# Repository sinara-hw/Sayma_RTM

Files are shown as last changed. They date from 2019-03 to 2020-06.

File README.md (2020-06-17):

# Sayma_RTM
RTM board with 8-channel GS/s DAC, 125MS/s ADC and flexible clock circuit

## Design Files

Design files (schematics, PCB layouts, BOMs) can be found at [Sayma_RTM/Releases](https://github.com/sinara-hw/Sayma_RTM/releases).

## Wiki

More information can be found on the [wiki](https://github.com/sinara-hw/Sayma_RTM/wiki).

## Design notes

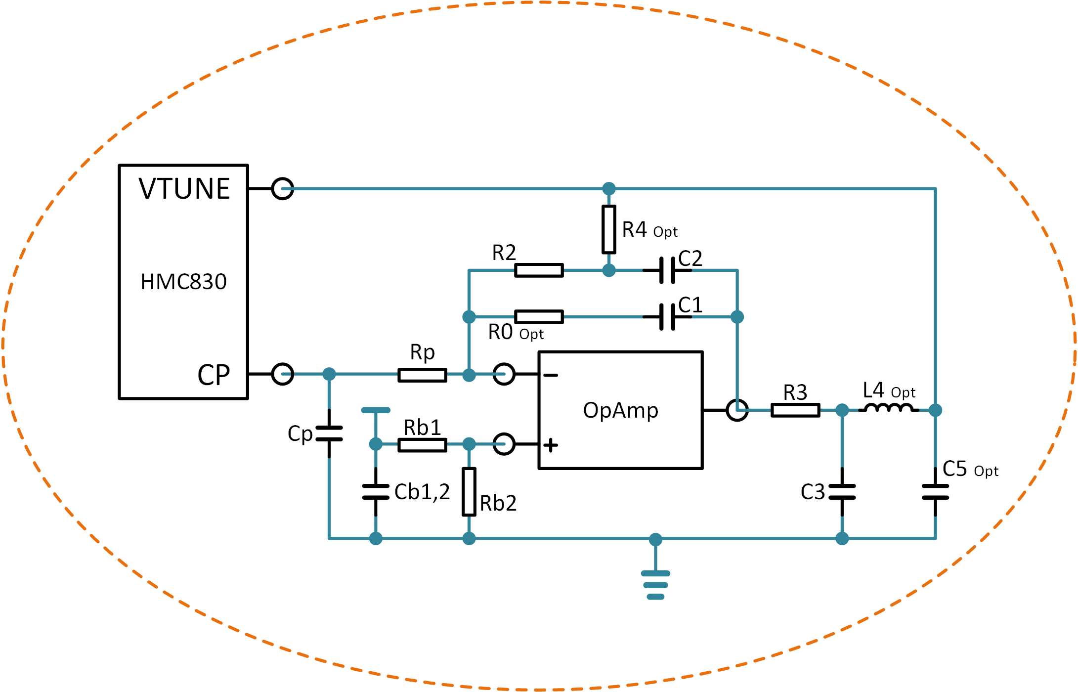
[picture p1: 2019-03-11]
HMC_830_FILTER.png

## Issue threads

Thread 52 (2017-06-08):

Sayma RTM - version 1 errata & tests

gkasprow, 2017-06-08:
Mechanical:
- [ ] SMA connector clearance with PCB edge - move it 100um outside
- [ ] Align J6, J7
- [ ] adjust 4-th upper  panel SMA hole
- [ ] move T7 away from the board edge
- [ ] J16, J18, J55, J66 i J64  not covered vias under connectors
- [ ] fix footprint of interdigitated capacitors

Silkscreen:
- [ ] Label on both sides of PCB for name of J1, J2, J73, J74.
- [ ] Dot marking pin1 J1, J2, J5, J7, J8, J9, J73, J74
- [ ] AFE slot names are not visible when Allaki are installed
- [ ] AFE slot names on both sides of PCB
- [ ] When the Allaki is mounted, the IN/OUT silkscreen faces the Sayma RTM PCB and makes it useless. Put it on the other layer that is visible when the card is mounted.
- [ ] add description to LD12, LD5, LD10, LD11, LD3

BOM:
- [x] R20, R21 = DNP
- [x] R269=1k

I2C:
- [x] replace MAX6642ATT90+T with MAX6642ATT98+T on RTM - change I2C address from 0x48 to 0x4C
- [x] connect some I2C pullups to P3V3 instead of P3V3MP

Power supply:
- [x] add another LDO for 1.2V (SVDD12)
- [x] connect 2V and 4V power module FB path to GND
- [x] fix power sequencing of negative SEPIC converter - either by addin 1uF cap to SS or starting negative converter after positive one.

Annotations:
- [x] IC57 address is 0x4B - change comment on schematics (PK: 0x49 is correct)
- [x] Zero-index all channels (DACs, ADCs, SFPs, SMAs, mezzanines, etc.)

JTAG:
- [ ] consider adding config FLASH
- [x] wire M[2:0] as 0b111 for slave serial configuration (#249)
- [x] swap FPGA config lines - DIN with MOSI (probably),
- [x] make sure config mode is set correctly.

Clocks:
- [x] HMC7043 has active high reset while SI5324 is active low. ~Add negator to one of them or tie HMC RST to GND~ give HMC7043 its own dedicated reset line to avoid noise issues during initialization.
- [x] short RSV* pins of HMC7043 to GND
- [x] add 10k pulldown on PLL chip CLK and SEN lines to make sure that logic state is well defined and FPGA can setup correct SPI protocol.
- [x] add CLK and SYSREF termination
- [x] SD pins of the LTC6957 clock buffer mus be grounded
- [x] HMC830 loop filter layout forms quite a large loop. Please try to make this smaller for EMI reasons.
- [x] HMC830 "NC" pins are currently floating in our design. Copy the [eval board](http://www.analog.com/media/en/technical-documentation/evaluation-documentation/hmc830lp6ge_eval_pcb_schematic.pdf) for these connections.
- [x] add HMC7043 output bias FET that disables clocks before configuration to get rid of RF noise
- [x] pullup/pulldown on HMC830 CS/clk line to prevent it from getting stuck in the wrong SPI mode
- [x] So, to be sure, I think we need separate pins for: Si5324 RST; HMC7043 RST; HMC7043 output enable FETs.
- [x]  We also need to make sure that all these lines (as well as the HMC830 CS) have the right pull ups/pull downs to put things in the correct default state on power up.
- [x] PLL locked LED for the HMC830, maybe leds for the clock muxes to indicate the clock source.

DAC:
- [x] missing 49R9 0201 resistors at the DAC outputs
- [x] connect VTT to 1.2V

Test points:
- [x] add GND and i2C testpoints
- [x] More test points, e.g. on all SPI busses, power rails, JTAG, PLL v tune, etc! Also some ground points to attach a scope to (maybe use pcb mounted test loops for some of these?)
- [x] Lots of test points (all SPI/I2C lines)

Other:
- [x] RTM: short VREFN and VREFP to GND, DNP C546 to enable internal ADC reference
- [ ]  consider adding 0R resistors between ICs and control lines (SPI, enable, etc) to allow easier debug/rework
- [x] add LVDS terminators (SSTL)

gkasprow, 2019-03-11:
moving mechanical issues to #46 and closing

Closed 2019-03-11.

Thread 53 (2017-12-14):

put BaseMod IN/OUT silkscreen on the other layer

sbourdeauducq, 2017-12-14:
When the Allaki is mounted, the IN/OUT silkscreen faces the Sayma RTM PCB and makes it useless. Put it on the other layer that is visible when the card is mounted.

gkasprow, 2019-03-11:
moved to #46

Closed 2019-03-11.

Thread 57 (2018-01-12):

Sayma v2: more test points

jbqubit, 2018-01-12:
From #408. @gkasprow More test points on Sayma v2.0, please! Particularly on all the SPI buses.

hartytp, 2019-03-14:
Could you have a go at this today please? I’ll do my review after it’s done

jbqubit, 2019-03-15:
@gkasprow Please implement change or give update. We'd all like to see pending changes to RTM complete and design frozen.

gkasprow, 2019-03-16:
Let's add missing test points to the issues and go on with the review.

hartytp, 2019-03-16:
Most important are the HMC830 and HMC7043 SPI. I'd also ideally like to have 0R resistors between the HMC chips and the FPGA for debugging (e.g. if we need to disconnect some signal).

Most analog power lines should have test points.

All I2C signals

hartytp, 2019-03-22:
AFE power supplies, I2C

gkasprow, 2019-04-08:
fixed

Closed 2019-04-08.

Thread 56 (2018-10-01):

sayma: heatsinks

hartytp, 2018-10-01:
With the DACs running at 2.4GHz they get scorching hot, even with decent air flow. Might be worth small heat sinks in the next version (also for the RTM FPGA?).

gkasprow, 2019-04-08:
I managed to place 17x17x2mm heat sinks. Even 3mm ones would fit but 2mm ones are COTS

gkasprow, 2019-04-08:
drawing
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

Closed 2019-04-08.

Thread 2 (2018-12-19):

test: measure DAC-DAC phase drift

jbqubit, 2018-12-19:
Measure and document relative DAC phase noise ([ST3](https://github.com/sinara-hw/sinara/issues/601)) for pair of Sayma in same rack. Compare three outputs.
- between channels on the same DAC
- between channels on adjacent DACs on the same RTM
- between channels on adjacent RTMs

Measure within 0.1 mHz of carrier using Microsemi 5125A.

jbqubit, 2018-12-19:
I asked analog Tech Support about drift. Here's their response.

> What is the dependence of signal propagation on temperature? Suppose I have two AD9154 chips that have a common dac clock and are initially phase aligned and producing 400 MHz tone. What is the relative phase if one AD9154 temperature increases by 1 C?

> I do not have a good answer here frankly. To quantify temperature drift, typically more than one part needs to be tested. We have little to no capacity to set this up at the moment.
Two AD9154’s (or any other identical generics) would drift in the same direction, and the rate would be similar as well, assuming the same production lot. So the relative phase will likely stay the same, especially with only 1*C increase. The really interesting aspect would be if there is a temp gradient between two devices from two different lots (monte carlo of sorts).
Temperature is inherently non-linear. So the slope due to a 1*C change will be different depending on the starting temp. Likely more so on the hot end. All in all, you would need to collect considerably more data than on a single part.  Going forward, we will have more temperature data on this class of parts.

So should check between several pairs of AD9154.

hartytp, 2018-12-19:
If you want to measure drift then the simplest way might be to just run the DACs at the same frequency then beat them against each other on a mixer and use a high-precision DMM to log the phase (given by the DC level). This is what we typically do and it works well.

Closed 2019-05-27.

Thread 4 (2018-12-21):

bigger FPGA

hartytp, 2018-12-21:
Context:
- there is currently a 15T on Sayma RTM which is pretty tiny
- for DRTIO we need to add Satman. Currently, that should be fine but it will require some optimisation to reduce firmware size
- adding a bigger FPGA will make it easier to get DRTIO going and reduces risks
- we can always move back to a smaller pin-compatible FPGA in a future design revision to save costs

@sbourdeauducq what size of FPGA do you think we should go for? 50T? Since this is still a prototype, let's err on the side of having too big an FPGA rather than too small.

@gkasprow what's the biggest pin-compatible FPGA we can stick on Sayma RTM?

jordens, 2018-12-21:
The 50T is pin compatible. But as mentioned before that might not be needed at all since the bitstream is the same except for the chip name.

hartytp, 2018-12-21:
So, the suggestion is bitstream hacking to make a 50T bitstream work on the 15T (which is the same silicon)? What's the cost difference between the two FPGAs? Is it worth the hassle of bitstream hacking?

hartytp, 2018-12-21:
Anyway, right now my preference is to go with whatever is least effort and gets RF out of Sayma quickest. Once Sayma works and we've gauged the level of interest we can focus more on cost optimisation.

jordens, 2018-12-21:
Place a 50T for now if the availabliity is ok and keep in mind that moving back to a 15T will require software infrastructure changes.

sbourdeauducq, 2018-12-23:
Well, with some optimization it may even fit within the 15T limitations that Xilinx made up. But 50T on proto sounds good.

jbqubit, 2018-12-26:
50T sounds like the lowest risk option. @gkasprow @marmeladapk Is it too late for this change to the BOM?

gkasprow, 2018-12-28:
I will check if they are 100% compatible. Usually this involves generation of new symbol and comparison pin by pin because not always migration is that straightforward.

marmeladapk, 2018-12-28:
According to Xilinx they should are pin compatible, however we should rerun power estimator and adjust power delivery accordingly.

gkasprow, 2018-12-28:
They usually are, but It happened to me that some IOs were swapped during migration to bigger chip or not present in smaller packages. So it is not always that simple.

gkasprow, 2019-01-01:
Can we use XC7A35T-1CSG325 instead?

gkasprow, 2019-01-01:
It's hard to get XC7A50T in CSG325 package

sbourdeauducq, 2019-01-06:
Also use a faster speed grade, -1 does not meet timing for 150MHz RTIO frequency.

sbourdeauducq, 2019-01-06:
15, 35 and 50 are the same silicon so it doesn't matter so much which one you pick...

jbqubit, 2019-01-08:
@sbourdeauducq   Please concur if you're happy with XC7A35T-2CSG325.

@gkasprow Are you comfortable that the risk is low enough for this change?

- [ ] re-run power estimator
- [ ] pin-by-pin check of new symbol

gkasprow, 2019-01-08:
The power supply is designed with a lot o margin. I can increase the current limit even by a factor of 5.

jbqubit, 2019-01-11:
@jordens Does your comment mean that @sbourdeauducq signed off on the use of 35T-3?

gkasprow, 2019-02-25:
XC7A35T-3CSG325 used.

kaolpr, 2019-07-18:
Long lead time for XC7A35T-3CSG325E (~14 weeks).

@sbourdeauducq @jordens Do you agree to use XC7A50T-3CSG325 only for the current production?

sbourdeauducq, 2019-07-18:
OK with me. The only important thing is the speed grade 3.

jbqubit, 2019-07-31:
XC7A50T-3CSG325 is fine by me.

jbqubit, 2019-08-19:
@gkasprow Please indicate how you're proceeding with this and close.

gkasprow, 2019-08-19:
We installed XC7A50T-3CSG325. It's the same silicon anyway.

Closed 2019-08-19.

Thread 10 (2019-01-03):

v2.0rc1 schematic cosmetics

hartytp, 2019-01-03:
Thanks for posting the new schematic revision @gkasprow! Posting small cosmetic issues here:
- [ ] remove annotation "Matching between the ... " and "SYSREF is matched to its CLK ... "
- [ ] annotaiton "other diff lines: LVDS" is a bit odd, since all other diff lines are now explicitly named LVDS. Just remove this line from the annotation?
- [ ] clarify what "shared IOs" means. Shared with what?
- [ ] Missing overview page?

hartytp, 2019-01-03:
- [ ] add annotation with frequency of OSC2

hartytp, 2019-01-03:
- [ ] HMC_RESET -> HMC830_RESET

hartytp, 2019-01-03:
- [ ] remove "SYSREF is matched to its CLK (a.k.a. DEVICECLK) to better than 100 ps" this no longer makes sense

atcher0, 2019-01-14:
- [ ] DAC_CFG buses are not zero-indexed
- [ ] HMC_RESET and HMC_SPI_GPIO lines are not used (CLK_DIST_CFG bus)
- [ ] HMC830_SPI_SEN != HMC_SPI_SEN (clock distribution page)
- [ ] no information about FPGA configuration settings
- [ ] many FPGA not connected pins are not marked NC
- [ ] OSC2 is placed on schematic without part number (+ no language describing use case)
- [ ] pages are not numbered consecutively

marmeladapk, 2019-01-14:
- [ ] Add annotations about TPSM84824: switching frequency (450 kHz) and soft start (2,4 ms)

gkasprow, 2019-02-26:
@hartytp what overview page would you like?

hartytp, 2019-02-26:
Something with a system BD that makes it clear what blocks we have in the design and how they connect together. Whatever you think is best though.

hartytp, 2019-03-16:
@gkasprow the new schematics are really beautiful. Very nicely annotated (comments about clocking regions for LVDS lines, colour coding for busses etc). Really well done on that :)

hartytp, 2019-03-16:
We can delete Weida's diagram from the schematics, since there isn't anything in there that isn't already in the schematics.

hartytp, 2019-03-16:
- [ ] worth adding an annotation on the HMC7043 that the FETs are used to avoid sending broadband noise to the FPGA before the IC is configured.

gkasprow, 2019-03-16:
Thanks. It's a side effect of switching to Altium :)

hartytp, 2019-03-16:
- [ ]  maybe add an annotation about the purpose of the bleed FETs on the HMC 830 supply (took me a minute to remember why they're there)

marmeladapk, 2019-04-05:
- [ ] P5V0_LDO_IN  (near IC15) should be P4V0...

hartytp, 2019-05-27:
@gkasprow are you happy with the overview page here? If so, let's close this issue.

marmeladapk, 2019-08-30:
[ ] Rename xVDD12 to xVDD13 on dac schematics?

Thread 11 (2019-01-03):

LT3045

hartytp, 2019-01-03:
- [x] Min output capacitor is 10uF (ensure decrease in capacitance from DC bias is taken into account)
- [x] check input capacitors as well as set capacitance (do we need a 100nF along with the electrolytic)?

gkasprow, 2019-02-27:
I replaced 4.7u with CC0805_22UF_16V_10%_X5R
The input cap is 4.7uF

Closed 2019-02-27.

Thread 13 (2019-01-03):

Sysref driving

hartytp, 2019-01-03:
@gkasprow how do you want to drive the AD9154 SYSREF? IIRC it should ideally be driven DC coupled with a common-mode voltage of 600mV (but someone should check this during the design review). That's not directly compatible with LVPECL without a RC termination network.

hartytp, 2019-01-03:
- [ ] even though this will be DC coupled, please ensure that there are suitable pads that can be used to add AC coupling capacitors later on if we find it necessary

hartytp, 2019-01-09:
cf https://github.com/sinara-hw/Sayma_RTM/issues/17

hartytp, 2019-01-09:
NB fwiw, the eval board has the SYSREF AC coupled, with a test point used to drive/probe the DC level.

IIRC the data sheet implies that SYSREF should be DC coupled where possible.

I would like to ensure that we can drive SYSREF either DC or AC coupled (choice by population options), with DC coupling being the default choice.

gkasprow, 2019-01-09:
If SYSREF is going to be a non-50% duty cycle, we must use DC coupling. We must make sure DAC accepts LVPECL common model

hartytp, 2019-01-09:
> We must make sure DAC accepts LVPECL common model

I don't think it does. IIRC the pin self-biases to 600mV (there is a figure in the data sheet that shows the simplified schematic for the input configuration), which is the common-mode voltage it's designed to work at. I don't think the common-mode voltage of LVPECL/CML will do the job.

marmeladapk, 2019-01-14:
Now SYSREF is AC coupled (and capacitors don't have values on schematics).

gkasprow, 2019-02-27:
well, not really. The high level of LVPECL can be even 2.4V. So out of the common mode of the DAC.
Do AC-coupling cause any issue? Certainly, we are not over-driving the inputs. I added the series 50Ohm resistors to lower the clock amplitude.

hartytp, 2019-02-27:
@gkasprow the thing I'm conscious of is that the default (self-biasing/AC coupling) DAC input common-mode bias voltage is only 600mV. I believe that it can work with other common-mode voltages, as indicated by the data sheet, but requires a larger swing to operate correctly. There is an equivalent circuit of the input stage that shows how this works.

So, I'm wary of DC coupling LVPECL in to the DAC unless we really think about it.

gkasprow, 2019-02-27:
So let's leave it as it is now.

hartytp, 2019-02-27:
@gkasprow can you confirm:
1. SYSREF is DC coupled into the DAC (although, let's make sure there are pads for AC coupling). IIRC currently SYSREF is AC coupled
2. DAC clocks and SYSREF are correctly terminated
3. which HMC7043 output standards is this designed to use (let's make sure that's annotated on the schematic)
4. that the common-mode voltage and voltage swing are appropriate for both the DAC clock and SYSREF

Once that's done we can close this issue

gkasprow, 2019-02-27:
to make SYSREF DC-coupled I have to lower the LVPECL output to less than 2V.
LVDS mode does not meet minimum 400mVpp DAC requirement.
So either we use CML mode that has VCC-1.6V common mode voltage or LVPECL with resistive divider.
I suggest using direct CML mode with series resistors that will reduce the swing
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
two 50R resistors should do the job and preserve common mode

gkasprow, 2019-02-27:
Let's keep the 200R DNP so we can always use them and replace 49R9 with 100nF and revert to AC coupling.

gkasprow, 2019-02-27:
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

hartytp, 2019-02-27:
Do you need to add termination to Vcc at the DAC then?

hartytp, 2019-02-27:
(if you're using CML for SYSREF that is)

hartytp, 2019-02-27:
Also, are you sure that 3.3-1.6=1.7V common-mode will work for the DAC SYSREF?

gkasprow, 2019-02-27:
It accepts it up to 2V so with reduced swing should work.

gkasprow, 2019-02-27:
HMC has internal termination for CML mode
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

hartytp, 2019-02-27:
Okay. Can you leave resistor pads so that we can make a divider between Vcc and GND if we need to modify the voltage swing/DC bias point.

gkasprow, 2019-02-27:
OK, I will add 2 DNP resistors to GND to make such divider.

Closed 2019-02-27.

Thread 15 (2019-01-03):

CDR clean 2

hartytp, 2019-01-03:
@sbourdeauducq do we need this, or can we just use use the MGT REF CLK? If we remove this signal, we can scrap a clock buffer to save some money/power/complexity in the clock tree

jbqubit, 2019-01-08:
@hartytp This isn't the time to try to optimize Sayma v2 money/power/complexity. The current plan is to keep the number of v1 vs v2 diffs to a minimum.

hartytp, 2019-01-08:
> The current plan is to keep the number of v1 vs v2 diffs to a minimum.

The purpose of this is not to minimise the number of design changes, it's to maximise the probability of arriving at a working design given the available resources.

While I appreciate the enthusiasm, I'm not connived the current spray of comments is entirely productive. Chill out and let's focus on having a solid technical strategy here rather than knee-jerk reactions.

hartytp, 2019-01-08:
Aside from the obvious point that unnecessary components can still introduce bugs and break an otherwise working design, they have to be checked carefully as part of the design review and then tested before the hardware is shipped. This all leads to delays. If this components is genuinely not going to be needed then it is likely to be quicker to remove it than to keep it.

jbqubit, 2019-01-08:
> I'm not connived the current spray of comments is entirely productive.

Please respond to my comments in the respective Issues.

jbqubit, 2019-01-09:
OK. Let's see what @sbourdeauducq says.

gkasprow, 2019-02-25:
Let's keep it as it is.

Closed 2019-02-25.

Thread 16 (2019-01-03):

WR?

hartytp, 2019-01-03:
@gkasprow would it be possible to add the same WR circuitry to the RTM that we have on the AMC? My long term aim it to be able to generate a high-stability DAC clock from the WR clock (via the AMC FPGA).

jbqubit, 2019-01-08:
@hartytp No more changes. Let @gkasprow focus on keeping track of bugs found during the design review. Please hold these suggestions until after Sayma v2.0.

hartytp, 2019-01-08:
@jbqubit

This is not a new addition to the project plan, it's finishing a job we've already agreed to do and have done most of the work for. There is no point at all having WR on the AMC if it's not also on the RTM, since that's where we actually need a good clock. The most time consuming part was designing WR for the AMC and reviewing that (already done), copying it to the RTM will be relatively quick.

jbqubit, 2019-01-09:
The point of a structured review process is to avoid pitfalls including feature creep. The time for lobbying to add new features to the design has passed. WR was added to the AMC as a secondary clock source to permit prototyping of DDMTD on Sinara hardware. It is not among my requirements in Sayma v2.0 and I'm not funding its development. As this change relates to a "long term" aspiration for Sayma let's discuss after Sayma v2.0 is working. It may be that it can be added to production hardware.

marmeladapk, 2019-01-09:
@jbqubit Well, technically I don't think that both m-labs and @hartytp signed of on HT1.5 in table. Also, I wouldn't call it a feature creep, this was discussed and, as @hartytp said, reviewed before. In schematics this change should be just replacing Si5324 sheet with one from AMC + adding I2C to FPGA. (@gkasprow correct me if I'm wrong)

TBH I'm not sure if there's a point in having WR only on AMC (I was surprised, that it wasn't present on RTM), after all we'd like to synchronize DAC output on Saymas, not just FPGA clocks. WR support on RTM could be of interest to other groups, which already use WR with MicroTCA.

Reviewers for clock schematics are me and @hartytp, and I just started checking issues in clock schematics. We can easily wait few more days and check something else in the meantime.

hartytp, 2019-01-09:
> WR was added to the AMC as a secondary clock source to permit prototyping of DDMTD on Sinara hardware

No, that's not why we added it here. WR will be prototyped on Kasli v1.2 not Sayma. I would not use a design as complex as Sayma to prototype this.

The point of adding WR on Sayma was to take the WR system we develop on Kasli and test its performance for clocking high-speed data converters. The clocking on Sayma, which will require high-stability reference clocks distributed to each RTM, is liable to turn into a bit of a mess without WR, which is why I'm keen to have a go at implementing it (and, indeed @dtcallcock an others have indicated that they would also value WR for this). We can't test this without WR on both the RTM and AMC. There is almost no point I can see in having WR on the AMC alone.

> It may be that it can be added to production hardware.

The whole point of prototyping is to prototype the system you want. Not to leave important sections (I would argue that in the long run WR will be important) out and then stick them on without testing for production.

> The point of a structured review process is to avoid pitfalls including feature creep. The time for lobbying to add new features to the design has passed.

This isn't adding a new feature, it's clarifying the scope of a feature already on the project plan. As far as I'm concerned, implementing WR on Sayma at all means implementing it on both AMC and RTM, otherwise it's just a waste of time.

WR is a block of hw that can be copied from one design to another relatively easily. The bulk of the time is spent designing that block, not copying it from the AMC to RTM. Putting it on the RTM is a small amount of extra work that allows us to make use of the work we've already done.

jordens, 2019-01-09:
@marmeladapk I think that WR on AMC is useful or even required for other users of Sayma_AMC.

sbourdeauducq, 2019-01-09:
> @hartytp No more changes.

@jbqubit What is the point of asking for reviews if you dismiss important comments like this one?
WR on RTM is needed to clock the DACs. Not having it there defeats its purpose entirely.

jordens, 2019-01-09:
I am a bit worried by the level of testing and integration that this (new) WR implementation will have seen (both in hardware and gateware/software) before we paste it on three boards roughly simultaneously. If we can't arrive at a trialed and tested design with integration at the PCB-level and the gateware/software level early enough, then we should at least invest significantly more time and resources into cleaning up, documenting, testing, reviewing, and integrating the current prototype.

hartytp, 2019-01-09:
@jordens that's fair.

The hardware has been quite extensively tested using the KC705 and DCXO evaluation boards. Phase noise and stability plots have already been posted. We've verified that it reliably acquires lock and maintains if over several days without issues (scope on infinite persist triggered from reference and monitoring recovered clock). I can provide additional documentation of the hardware configuration, for example by giving a list of FPGA connections used to implement WR if that helps.

The gateware/software for this was straight verilog + xilinx cores e.g. for I2C. A migen/misoc port is underway at the moment. FWIW, I can't think of any issues with Artiq integration that could be major showstoppers, beyond the usual requirements for transceiver/fabric clocking, but there is always a risk that we've missed something.

The gateware is mainly just a straightforward implementation of the CERN WR cores. The changes are:
- higher order loop filter
- loop filter implemented in DSP instead of soft CPU
- I2C dac + VCOs replaced with I2C DCXOs (programming words are longer than for DACs, so I2C busses must run at higher clock rates, but still below the max 1MHz clock rate)

One thing that does need doing is pulling all the data scattered across various places into a write up. We'll do that, but might not manage it before the Sayma deadline which is quite tight.

sbourdeauducq, 2019-02-02:
The pitiful results of some DDMTD attempts on the Ultrascale FPGA makes me think that we have to be careful about how we time signals with FPGAs. We cannot expect to route time-critical signals without precautions all around a large, noisy FPGA and get good performance.

* DDMTD on Ultrascale with one clock from the GTH and one clock from an I/O bank exhibits high peak-to-peak jitter and unexplained intermittent skews that are not corrected by averaging, when the FPGA is loaded by integrating SAWG. This renders it pretty much unusable in this configuration, unless workarounds are found (discussing with Xilinx).
* DDMTD on Ultrascale with both clocks from the same IO bank, and one on a GC pin, works a lot better, but I have done only limited testing (this is not interesting for Sayma DAC synchronization, since I could not figure out a good hardware hack to get relevant clocks with deterministic phases in the same IO bank).
* DDMTD on Artix-7 with both clocks from the same IO bank, and one on a GC pin, is looking good, no DDMTD failure found by firmware diagnostics after 506 Sayma reboots, reported jitter is low.

So we should make sure that all time-critical paths stay in the same I/O bank and also signals that go to MMCMs, BUFGs, etc. are using the correct GC pins.

Some more radical options:
* connect a AMC backplane transceiver pair to the RTM GTP (through the AMC and RTM connector), so we can bypass the Ultrascale FPGA for all time-critical functions if needed (i.e. run DRTIO directly from Metlino to Sayma RTM).
* add a small FPGA to Metlino that handles time-critical functions, like managing the WR PLL.

hartytp, 2019-02-02:
@sbourdeauducq thanks for the updates, that's helpful.

> DDMTD on Ultrascale with one clock from the GTH and one clock from an I/O bank exhibits high peak-to-peak jitter and unexplained intermittent skews that are not corrected by averaging, when the FPGA is loaded by integrating SAWG. This renders it pretty much unusable in this configuration, unless workarounds are found (discussing with Xilinx).

@WeiDaZhang correct me if I'm wrong, but that's a bit concerning isn't it, since this is the configuration that we have to use for clock recovery on Sayma (since one clock originates in the transceiver).

We did a lot of testing on the Kintex 7 and didn't see effects like this, but have no experience with ultrascale FPGAs.

> So we should make sure that all time-critical paths stay in the same I/O bank and also signals that go to MMCMs, BUFGs, etc. are using the correct GC pins.

I think the proposed implementation of DDMTD-based clock recovery on Sayma does this as far as possible (although if you see room for improvement then let me know!).

> connect a AMC backplane transceiver pair to the RTM GTP (through the AMC and RTM connector), so we can bypass the Ultrascale FPGA for all time-critical functions if needed (i.e. run DRTIO directly from Metlino to Sayma RTM).
>
> add a small FPGA to Metlino that handles time-critical functions, like managing the WR PLL.

The idea of adding timing FPGA on Metlino is potentially quite a nice one, might be worth trying to keep that option open as a future direction. I'd really like to build a version of Kasli with DDMTD + DCXO asap so we can develop the concept and give it a proper test in a simpler system before we make too many decisions about what to do on Metlino.

What about systems where we don't use Metlino, and control Sayma via SFP (this will be our primary use case for the foreseeable future)? In that case, I don't see an obvious remedy to avoid the ultra scale FPGA.

gkasprow, 2019-02-27:
I added WR to the RTM side.
Anything else do to in this issue?

hartytp, 2019-02-27:
Nope

Closed 2019-02-27.

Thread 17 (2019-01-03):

delay line termination

hartytp, 2019-01-03:
I don't understand the termination for the digital delay line:
- Why are R127 and R128 used for *DC* coupled LVPECL?
- Why is R129 necessary?
- Don't we need to apply a Vcc-2V=1V3 DC bias to the Vtt pin? Just use one of the standard RC networks for this

hartytp, 2019-01-03:
Similarly for the DFF:
- IIRC the CK and D lines of the MC100EP31DTG are **not** internally 50R terminated (they just have 75k) pull downs. So external termination is required
- there is a version of the DFF that has a differential LVPECL clock input. We might as well use that since we have a differential driver available (don't worry about this if it's hard to do, but it would be nice since better emi resistance)
- The CK input needs appropriate DC biasing since it's DC coupled (this could be AC coupled if it's easier)

gkasprow, 2019-02-25:
not relevant anymore

Closed 2019-02-25.

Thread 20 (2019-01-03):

clock probe points

hartytp, 2019-01-03:
Add UFL test points on the unused output of IC46 (AC coupled, with 200R biasing resistors). During noise debugging, it's really useful to be able to verify the clock noise at each step of the clock tree. We can DNP these in a future design revision

gkasprow, 2019-02-25:
done

Closed 2019-02-25.

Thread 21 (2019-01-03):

adf PLL review

hartytp, 2019-01-03:
Will complete this after testing. Howerver....
- [ ] remove the bias inductors. They increase the power by 1dB at high frequencies but kill the power at low frequencies. Not worth the hassle
- [ ] review the HMC1060LP3E connections
- [ ] @gkasprow if possible, I'd like to scrap IC45. The ADF PLL has two outputs, which we can use to drive the DACs directly
- [ ]  after testing the ADF pll we should consider scrapping the HMC830. NB if we keep it then we need to route the HMC830 output to the RTM FPGA for phase measurements to synchronise the PLL output divider

hartytp, 2019-01-03:
If we scrap the mux then just use some weak capacitors to pick off some power for diagnostic UFLs (same as you're doing for the HMC830)

jbqubit, 2019-01-08:
> after testing the ADF pll we should consider scrapping the HMC830

No. The project plan calls for layout of HMC830. Wait until after v2.0 to jettison HMC830.

hartytp, 2019-01-08:
Let's see how I get on with the AF PLL before making a final call on this. The clock path is critical and the more components we cut out the more likely it is to actually work.

hartytp, 2019-01-08:
Also, as Greg's pointed out elsewhere, while it's easy to add things to the schematic, doing a good layout with minimal cross-talk is much harder and more time consuming (not to mention, quicker to review and test).

Right now, my preferred option would be this:
- implement the ADF as the only PLL, connecting the two outputs to the two DACs directly (subject to testing by me, verifying logic levels etc)
- use solder jumpers to allow the DAC clocks to be driven by an external source
- add a gpio header with power that connects to the FPGA
- if we do have any issues then we can bodge on a simple PCB with just an HMC830 + output buffer that connects via header/coax to the board. That gives us a simple risk-mitigation plan without having to stuff the main Sayma design with layers of cruft.

gkasprow, 2019-01-09:
We have a lot of space on board and HMC part is already routed.

hartytp, 2019-01-09:
@gkasprow Okay. I was just hoping to scrap the clock mux.

How about a different compromise:
- We connect the two ADF outputs directly to the two DACs (no fanout buffer)
- we use solder jumpers to allow the ADF outputs to be disconnected and the DAC clocks to be driven from UFL connectors (useful anyway for injecting external DAC clocks and other diagnostics)
- we leave the HMC830 and fanout buffer
- we connect the fanout buffer outputs to UFL connectors
- that way, to use the HMC830 users just add some short UFL jumpers. This is inconvenient, but gives a good redundancy plan

hartytp, 2019-01-09:
Note that the current design is somewhat problematic for DAC clock frequencies below 1.5GHz when using the HMC830 since the output divider is not synchronised.

It should be possible to get around this by using the AD9154 as a phase detector to infer the startup phase of the HMC830 output dividers and reset the PLL until the dividers start with the right phase, but that has not been demonstrated yet. Without testing, it is not clear whether this will work, so it's a serious risk with the HMC830.

We also have not demonstrated the HMC830 operating reliably yet. To get it to work reliably would require extra power-cycling FETs, which aren't in the current RTM schematic IIRC. Even once they're added, we won't know for sure that it all works without further testing.

All in all, it's not clear to me that the HMC830 offers a lower risk path, since we have not yet demonstrated it working really robustly. Moreover, it has known issues (unsynchronised output dividers) so I feel we're better focusing on getting the ADF PLL working really well and only keeping the HMC830 as a real last resort.

gkasprow, 2019-02-25:
it looks that this issue is no more relevant and we can close it.

Closed 2019-02-25.

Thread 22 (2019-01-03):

HMC830

hartytp, 2019-01-03:
verify that connections match the eval board schematic

hartytp, 2019-01-11:
:+1:

marmeladapk, 2019-01-11:
I only wonder how will HMC830 behave, when it gets high state on SPI lines while powered down. Clock could also be problematic.

marmeladapk, 2019-01-14:
Credit @atcher0, this one is pretty critical, ping @gkasprow

> HMC830_SPI_SEN != HMC_SPI_SEN (clock distribution page)

gkasprow, 2019-02-25:
One must simply make sure that when EN_PWR_HMC830 is low, other SPI signals must be low as well.
I added discharge resistors to the HMC830 supply rails and transistor that disables ADCLK948 pulldowns.
So we make sure that the HMC supply will fall to zero.

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

Closed 2019-02-25.

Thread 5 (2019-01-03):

unfloat SMA grounds

hartytp, 2019-01-03:
- [x] R186 -> 0R

hartytp, 2019-01-03:
- [ ] Add annotation that the 0R resistors can be replaced with 100k to isolate grounds

Closed 2019-02-25.

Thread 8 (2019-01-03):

Si5324 I2C

hartytp, 2019-01-03:
@gkasprow am I correct in thinking that currently the Si5324 I2C bus is driven by the AMC and not by the RTM FPGA. @sbourdeauducq correct me if I'm wrong, but in the new revision, don't we want the Si5324 I2C driven by the RTM FPGA?

gkasprow, 2019-02-25:
Any of FPGAs can drive it. On both AMC and RTM side, the FPGA has access to the whole I2C network.
AMC I2C network has access to the RTM I2C network as well.

Closed 2019-02-25.

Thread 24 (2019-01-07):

FPGA_CFG_DIN

tprzywoz, 2019-01-07:
Should be connected to DIN (pin L17) not MOSI (K16)

gkasprow, 2019-01-07:
Are U sure?
It was connected like this in first revision and did not work.
We do not use master serial with FLASH but slave serial.
Bitstream is loaded by AMC FPGA.
So  the data goes to D00.

Closed 2019-02-25.

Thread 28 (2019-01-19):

ADF4356 testing writeup

hartytp, 2019-01-19:
Test setup:
- using ADF4356 eval board
  - clock applied single-ended to REFINA SMA at +6dBm
  - cut traces to disconnect on board XO from PLL ref in
  - remove R7 to power down XO
  - replace R6 with 47R and short REFINB side to GND
  - remove L1, L2, L5, L6
  - supply from external 5V supply
  - looking at RFOUTA/RFOUTB on fast scope via AC-coupled balun (TCM2-43X+)
  - driving SPI bus from Kasli using core device driver (to do: post code)

To check for phase determinism, I'm:
- clocking from 150MHz reference
- using power splitter to pick off some reference power to triggering a fast scope from
- looking at RFOUTA on the scope on infinite persist
- reset sequence is: pause scope acquisition; turn reference off; disconnect PLL power; wait a couple of seconds; reconnect PLL power; turn reference back on; reprogram PLL and wait to lock; resume scope acquisition
- expectation: if phase is not deterministic then on each reset the 600MHz RF will move w.r.t. the 150MHz in random increments of 1/4.8GHz=208ps.
- observation: over 10 resets, the RF phase is constant to within the ~100ps jitter of my scope

hartytp, 2019-01-19:
One comment about this: the PLL prescalers mean that the minimum N divider is 23. As a result, for feedback through the output divider, the minimum divide ratio is 23*output divider. e.g. for 600MHz output divider is 8, so minimum divider is 184. Given that the VCO runs at 4.8GHz, this gives a required PFD frequency of 26MHz. That's okay, but will result in worse noise (usually 3dB per factor of 2 in PFD frequency).

In the first instance, I suggest that we just live with slightly worse in-loop phase noise, as it will still be fine (I'll post a noise model later on).

Longer-term we have two resolutions:
1. Run at higher DAC clocks using interpolation (assuming this doesn't hit a bug in the DACs)
2. Do not do the feedback through the output divider. Attempt to use the DAC as a phase detector to determine the PLL output phase. Then, reset the PLL until it starts with the desired phase. This should work, but will require some development. This will be easy to play with on the new Sayma board assuming all DAC/PLL control is done from kernels...
-

hartytp, 2019-01-19:
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

https://www.analog.com/en/technical-articles/phase-alignment-and-control-on-the-adf4356-5356-devices.html#

NB PLL phase temp co is approx 2.5ps/C, which is not negligible...

hartytp, 2019-01-19:
uurgh...looking closer, there is something funny going on with the phase. It seems to be non-reproducible at the 50ps level.

Potentially relevant from the above article

> Given that the ADF4356 PLL and VCO contain 1024 differing VCO bands, it is important that this uncertainty is eliminated by using the manual calibration override procedure.

hartytp, 2019-01-19:
(although, given that the VCO is in a feedback loop and the article is about feedback after the output divider, it's not clear to me what the VCO hand has to do with anything).

hartytp, 2019-01-19:
looks like this is what we're hitting: https://ez.analog.com/rf/f/q-a/71780/adf5355-integer-n-phase-synchronization. As the top post says, there is clearly more to these chips than documented or shown on the BDs.

I'll come back to this on Monday. The only thing I can think of is disabling the VCO auto cal. No idea whatsoever why that would make a difference, but some of the comments indicate it could be relevant.

If that doesn't work then I think the conclusion is going to have to be that this PLL is completely unacceptable for our use cases. At least with the HMC830 operating in integer-N mode AFAICT the phase jumps were an integer number of VCO cycles, so it should be possible to use a phase detector to take it out.

I think the plan needs to be this: I'll focus on this on Monday. If by the end of Monday I'm still baffled, we ditch this PLL and focus on using the HMC830.

hartytp, 2019-01-21:
Here is the code I used for these tests.

```python
""" RTIO driver for the Analog Devices Inc. ADF4356 PLLs.

Output event replacement is not supported; issuing commands at the same
time is an error.
"""

from numpy import int32

from artiq.language.core import kernel, portable, delay
from artiq.language.units import ns, us, ms, MHz
from artiq.coredevice import spi2 as spi

# to do: output n and r div to see duty cycle and also reset of dividers...

SPI_ADF4356_CONFIG = (0*spi.SPI_OFFLINE | 1*spi.SPI_END |
                      0*spi.SPI_INPUT | 0*spi.SPI_CS_POLARITY |
                      0*spi.SPI_CLK_POLARITY | 0*spi.SPI_CLK_PHASE |
                      0*spi.SPI_LSB_FIRST | 0*spi.SPI_HALF_DUPLEX)

@portable
def ceil(x):
    return int32(x) if (float(int32(x)) == x) else (int32(x) + 1)

class ADF4356:
    """ Driver for Analog Devices Inc. ADF4356 PLLs.

    :param spi_device: SPI bus device name
    :param le_device: SPI load enable channel name
    :param muxout_device: PLL muxout device channel name (used for lock detect)
    :param ref_div2: enable the reference divide by 2 block
    :param ref_doubler: enable the reference double
    :param ref_cnt: reference divider
    :param f_ref: reference clock frequency (Hz, default: 125e6)
    :param chip_select: value to drive on SPI chip select lines during
      transactions (default: 1)
    :param div_write: SPI clock divider for write operations (default: 8,
      50MHz max SPI clock with {t_high, t_low} >=10ns)
    """
    kernel_invariants = {"bus", "load", "muxout", "ref_cnt", "ref_div2",
                         "ref_doubler", "f_ref", "f_pfd", "adc_clk_div" ,
                         "adc_t_sample", "chip_select", "div_write", "core"}

    min_ref_freq = 10e6
    max_ref_freq = 250e6  # SE ref, no doubler
    min_vco_freq = 3.4e9
    max_vco_freq = 6.8e9
    max_pfd_freq = 125e6
    max_out_div = 64
    max_ref_cnt = 1023
    min_n_45 = 0x17
    max_n_45 = 0x7fff
    min_n_89 = 0x4b
    max_n_89 = 0xffff
    max_band_sel_timeout = 0x3ff
    mod1 = 0x1000000  # fixed numerator for primary modulus
    idn = 0xad  # magic PLL identifier

    # muxout options
    muxout_three_state = 0x0
    muxout_dvdd = 0x1
    muxout_gnd = 0x2
    muxout_analog_ld = 0x5
    muxout_digital_ld = 0x6

    reg3 = 1 << 25  # phase sync
    reg5 = 0x80002  # magic!
    reg8 = 0x1559656  # magic!
    reg11 = 0x61200 | (0 << 20)  # VCO band hold off
    reg12 = 0x5f | (1048575 << 8)  # phase resync

    Icp = 0.9  # charge pump current (mA)

    def __init__(self, dmgr, spi_device, le_device, muxout_device,
                 ref_cnt, ref_div2, ref_doubler, chip_select=1, div_write=8,
                 f_ref=125e6, core="core"):
        self.bus = dmgr.get(spi_device)
        self.load = dmgr.get(le_device)
        self.muxout = dmgr.get(muxout_device)
        self.f_ref = f_ref
        self.chip_select = chip_select
        self.div_write = div_write
        self.core = dmgr.get(core)

        if not (self.min_ref_freq <= f_ref <= self.max_ref_freq):
            raise ValueError("Unsupported reference frequency")
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
hartytp, 2019-01-21:
Since I've got this PLL setup already, I'll make a quick phase temperature measurement tomorrow with a hot air gun and check how the temp co depends on Icp and f_pfd. If we see a strong dependence of the phase stability on the loop gain (Icp/f_pfd) then it tells us that the phase stability is dominated by the loop's ability to drive the PFD error signal to zero. As a result, we should implement an active (3rd order) loop on Sayma (same as we do for WR). We can take this design from @WeiDaZhang's clock mezzanine design.

However, we don't have the bandwidth/resources to exhaustively characterise multiple PLL chips. So, after that, we have to make a decision about which PLL chip we want to use before we can move forward.

If the HMC830 is our choice then I think the order of priorities needs to be:
1. using an eval board, measure the size of the HMC830 output band-select glitches when used in fundamental mode (no output divider). Verify that these go away when the PLL auto calibration is disabled.
2. using an eval board make a quick phase temperature stability measurement (passive loop filter)
3. Verify that we can use the DAC as a phase comparator to allow us to make the HMC830 output phase deterministic when the output divider is used. I'll need help from @sbourdeauducq to do this, since it requires porting rust code to kernels
4. (can be done in parallel with 3) prototype the active loop filter using an eval board

If we don't go for the HMC830 then we need to decide on the work package for the ADF PLL.

Before tackling this, I'll write up the clocking plans so that M-Labs can sign off on them...

hartytp, 2019-01-30:
@sbourdeauducq  asked

> have you tested the HMC830 for the same phase instability issues that the ADF chip has? also, what is the level of those instabilities? I'm doing some tests with DAC synch now and getting interesting results, so, if there are issue swith the HMC stability, what level of precision should I be looking at?

On the ADF4356 I observed variations in the output phase across power cycles that were generally around 50ps, but pk-pk over 10 or so power cycles was (from memory) closer to 200ps.

My understanding of the origins of these glitches is as follows:
- by default (this can be disabled) each time the PLL is locked/restarted it undergoes an automatic calibration, which selects an appropriate VCO band to use (combination of selection of the physical VCO core, but also switching in and out capacitors, changing biassing, etc).
- the VCO tuning input is has a significant (but unspecified) band-dependent leakage current, so it's not a high-impedance node at DC
- to achieve the correct output frequency the VCO requires a band-dependent bias voltage supplied by the loop filter output. Since our loop filter is passive, generating this bias voltage requires a finite phase offset at the charge pump
- there are probably other related effects that I haven't thought of/read about
- the upshot of this is that there is a phase offset at the PLL output that depends on the VCO band. To eliminate this, the VCO auto-tuning should be run once to determine the appropriate VCO band and then manually set to this future band. (I haven't tried this mode of operation on the HMC830, so we should really play with it asap)
- even with the VCO band manually selected, these effects still probably degrade the output phase stability/temp co (guess, I haven't got data to prove it).
- using an active loop filter should eliminate these effects and also improve the temp co/phase stability (we have anecdotal evidence for this from our tests of Weida's PLL mezzanine, but not a careful design study I can post). Ultimately, we should try to measure this on Sayma since the phase stability is critical for many ion trap applications
- the size of these effects depends strongly on the PLL configuration. higher charge pump currents, higher PFD frequencies and tighter loop filters should all reduce their magnitude. The ADF4356 tests I posted were in a suboptimal configuration (using the eval board's default loop filter and CP current, low PFD required to use the output divider, etc). The size of these effects will also be strongly dependent on unspecified properties of the PLL chip
- since the HMC830 on Sayma was carefully optimized, it seems likely that the glitches will be much smaller. How small is anyone's guess (1ps - 100ps???) and needs measurements. @sbourdeauducq if you have concerns then put the VCO into manual band select. IIRC the HMC830 provides a relatively simple means of doing that...

I have not made a comparable measurement on the HMC830, although anecdotally I believe that

Closed 2019-01-22.

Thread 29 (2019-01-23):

Sayma v2.0 clocking/synchronisation write up

hartytp, 2019-01-23:
Thanks to @jordens for an extremely useful discussion about this! https://freenode.irclog.whitequark.org/m-labs/2019-01-22 https://freenode.irclog.whitequark.org/m-labs/2019-01-23

Below is my proposed clocking/synchronisation scheme for Sayma. There are plenty of other ways of skinning this cat; the recommendations here are influenced by my competences, biases and the kit I have in my lab right now.

- Reference:
    - f_ref = f_rio_coarse
    - reference clock must be phase locked to the RTIO clock (stable to <<8ns)
    - two reference sources to be supported in hardware using a mux (ADCLK948 or similar): external (SMA/MCX); or internal/WR
    - until WR implemented and tested, external reference will be the only option supported in software
- DAC clock
    - DAC clock (typically between 600MHz and 2.4GHz) generated by on-board PLL
    - fanout buffer used to route DAC clock is a mux (ADCLK948 or similar)
    - second mux input attached to UFL/MMCX connectors that can be used to inject an external clock if required as a fall-back in case of unforeseen issues with the PLL (in which case the user takes responsibility for ensuring phase locking/stability w.r.t. the reference clock)
    - DAC clock output phase must be deterministic w.r.t. the reference clock and have suitably low drift both for synchronisation (drift << 1 DAC clock period) and for the user's particular requirements (usually <=1ps for ion traps)
    - DAC clock PLL operated in integer-N mode so phase is deterministic apart from any unsynchronised output dividers or device imperfections/"analog effects" (VCO leakage, drift etc)
    - test ongoing to characterise the device imperfections. Provisionally it looks like we'll want to manually set the VCO band and use an active (3rd order) loop filter. Also highly desirable to operate the PFD at the max possible frequency. Need to measure phase v temp coefficient for PLL (and also for DAC since that may well limit the overall system performance)
    - Plans for overcoming unsynchronised output dividers (not necessarily in order of preference)
    - Plan A: operate PLL in "fundamental" mode (no output divider) and use DAC interpolation
        - For the HMC830, the VCO range is 1.5GHz to 3GHz, so this only works when the DAC is used in interpolation mode (e.g. >=2GHz clock)
        - For the ADF PLL, the VCO range is 3.4 to 6.8GHz, so this is not possible
        - Risks: a DAC bug that prevents synchronisation at this clock rate
    - Plan B: manually synchronise the PLL output divider
        - DAC clock output phase indeterminism quantized in multiples of the VCO period
        - Desirable to use a PLL with lower VCO frequency as phase quantized in larger steps (makes HMC830 preferable to ADF)
        - measure the PLL start-up phase and reset the PLL (e.g. toggle divider value) until we achieve the desired phase
        - Needs an external phase comparator. Various ways to do this, one possibility is to use the DAC SYSREF. Another is to use the FPGA. Let's configure the hw to allow both.
        - if using the DAC: at start-up, scan sysref delay and find the transitions. If these are not where we expect them to be then reset the divider and try again. Relies on the SYSREF detection being long-term stable to better than 1 period of the VCO, but if this isn't the case then we're never going to be able to sync the DAC at max clock rate and so should rethink the design anyway
        - ideally, should be demonstrated using v1.0 hw (work in progress)
    - Plan C:
        - Use a PLL with synchronised output divider
        - I can see two paths to do this
            - 1. PLL with feedback after the output divider
                - either make our own PLL (e.g. combine PLL with external PFD) or use the ADF4356 or similar, which can do this internally
                - ADF pre scaler requirements mean we'd have to operate the PFD at around 20MHz for 600MHz clock. Not a killer, but annoyingly low (worse for noise and drift)
                - Basic idea demonstrated on ADF4356 evaluation hw, but analog effects/device imperfections need further investigations (but that's true for any approach)
                - rolling our own PLL might give best drift performance but would need careful prototyping. Might be best to press ahead with Sayma v2.0 as is and demonstrate this on an external mezzanine board if required (use the mux to inject it into the DAC clock tree)
            - 2. Use a PLL with a synchronisable output divider (or use an external output divider with SYNC pin)
                - If we're not careful, we end up with another 2GHz sync problem and need more delay lines etc, more complexity, doesn't seem worth it
                - possible exception would be to use the HMC7044, which has a simpler sync mechanism (can sync of ref clock). However, that would need testing and I have separate concerns about that chip (e.g. IIRC, it's only possible to use the low-frequency sync input if we also use a 2-loop PLL, which is nasty for drift etc)
    - Given the above I would (weakly) advocate for: use HMC830 as our PLL. Aim for plan A initially, with plan B as a fall-back. If even that doesn't work then we can build a separate PLL board and hook it up via coax/IDCs to inject the DAC clock
- SYSREF
    - SYSREF generated on RTM FPGA using a SERDES TTL Phy
    - routed to a retiming DFF on the RTM. DFF clocked directly from the ref clk fanout
    - low-jitter retimed SYSREF goes to digital delay lines, then routed to each DAC (DC coupled)
    - two synchronisation issues:
        - A make FPGA SYSREF meet S/H timings at the DFF
            - relatively "easy" problem since we have an ~8ns period
            - I would expect that this is something that can be properly constrained in gateware so that we can use a single calibration (e.g. scope) for all boards across PVT
            - If we need to, we can implement a calibration scan, for example by: produce a 1mu (1ns for 125MHz f_rtio) wide pulse from the FPGA and scan the delay in 1mu increments. Ask the DAC whether it's seen a SYSREF edge or not. This allows us to locate the sampling window. We could also route a copy of the retimed SYSREF signal to a RTM FPGA input to allow us to do the calibration without involving the DAC (but requires more HW on the board)
        - B make the retimed SYSREF meet S/H timings at the DAC
            - this is the "harder" part of the problem, since timing window much narrower (must meet S/H on a 2.4GHz clock)
            - use DAC as a phase comparator (one shot-then-monitor mode) sweep SYSREF delay and find the edges. Put SYSREF delay in the middle of this window. Store a seed value to make this repeatable across boots
            - risk: drifts in the delay lines etc. Preliminary tests suggest that this won't be a problem over a decent range of VT
            - risk: some DAC issue that breaks sync at higher clock rates.
- FPGA
    - RTM FPGA clocked from recovered DRTIO clock. This must be stable w.r.t. the ref clock to <<8ns
    - AMC FPGA fabric + transceivers clocked from DRTIO CDR clock
    - Need to ensure that we have a suitable PLL on the AMC to generate the required transceiver clocks
    - AMC SYSREF signal either routed from the RTM FPGA to the AMC FPGA via the AMC <-> RTM connector or (more likely) generated internally from the rtio clock

jordens, 2019-01-23:
Apart from the things discussed on IRC:

* It would be helpful to get an output from the RTM ref clock fanout to the AMC FPGA (and the RTM FPGA). Even if it is only for debugging/bandaid to decouple the JESD/SYNC stuff from DRTIO ref clk reconstruction.
* It is apparently recommended to disable the CP leakage current compensation when changing/setting frequency at high PFD frequencies. I.e. large PFD frequencies and large CP leakage current look problematic. (Hittite PLL operating guide).

jordens, 2019-01-24:
Right. That was fractional.

hartytp, 2019-02-20:
>  I assume we stay with HMC830 and HMC7043?

Yes.

Closed 2019-02-27.

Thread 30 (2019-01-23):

DAC clock PLL

hartytp, 2019-01-23:
To do:
- [x] all sign off on choice of HMC830
- [x] either add power cycler or use LDO with enable pin and add drain resistors
- [ ] add DNPd pads for 3rd order active loop filter
- [ ] route output of DAC clock fanout to FPGA via DFF. DFF clock driven by DAC clock, data input driven by FPGA to allow gating. DFF output driven to diff input in FPGA. Used for S/H validation. @sbourdeauducq to sign off on this part of the design, check frequency range, voltage standards on FPGA
- [ ] add mounting holes and IDC that can be used to for external clock board. Add UFL/MMCX to unused mux input

hartytp, 2019-01-29:
@gkasprow are you happy with all the items on the list above?

One thing we didn't discuss on the phone was the HMC830 loop filter. Based on our experience here, passive loop filters are generally not the best for phase critical applications, so it's worth leaving ourselves the option of adding an active loop filter. Can be DNPd pads for now and we'll prototype it once we have the new hw.

hartytp, 2019-02-26:
>     * route output of DAC clock fanout to FPGA via DFF. DFF clock driven by DAC clock, data input driven by FPGA to allow gating. DFF output driven to diff input in FPGA. Used for S/H validation. @sbourdeauducq to sign off on this part of the design, check frequency range, voltage standards on FPGA

@sbourdeauducq I assume we no longer need this, as the DAC seems to behave fine at max clock rate...

hartytp, 2019-02-26:
> add mounting holes and IDC that can be used to for external clock board. Add UFL/MMCX to unused mux input

If we're happy with the HMC830, we can also scrap this item -- although, I still think that exposing some GPIO and supply voltages on pin header would be a very good idea

gkasprow, 2019-02-27:
we will keep 2V5 IO pin header so we can use it for any purpose.

gkasprow, 2019-02-27:
What loop filter would you like for HMC? Active one? So shall I add RC place holders and opamp?
Any suggestions on opamp?

hartytp, 2019-02-27:
I'd like to have a passive loop filter (same one we currently have) fitted by default, but the pads there so we can add an active loop filter later on if testing indicates that it would help. Just use a generic SOIC8 OpAmp footprint for now.

@WeiDaZhang is thinking about active loop filters right now, and will post a recommendation for a topology to use soon.

Closed 2019-03-05.

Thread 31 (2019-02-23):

Sayma RTMv2 mechanics

gkasprow, 2019-02-23:
I'm doing component placement of the v2 board. Unfortunately, I had to almost entirely unroute the RTM board - only the supply section and DACs remained intact.
So, this is an occasion to optimize the component placement.

- I will place part of the clocking section mostly on the top layer. Only HMC7043 would be placed on bottom side as it was originally. I want to avoid routing long traces for the DAC clock.
- The clock input SMA must be in the middle of the front panel. There is no other way to install it.
- one would need to remove the front panel to replace the AFE modules. Another option is to unscrew the panel, remove the module keeping the panel attached to the RTM board.
- I will move the FPGA towards board centre to make routing LVDS lines easier
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

gkasprow, 2019-02-23:
I can place the SMA input connector in line with other SMAs using the right-angle connector.

gkasprow, 2019-02-23:
Actually, it's hard to make it ideally in-line even with low profile RA SMA connector
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

hartytp, 2019-02-23:
I’m not fussed about the clock SMA being inline with the other SMAs. Can even be MCX if that helps. Let’s just make sure all clock traces are as short as possible and we keep plls away from noisy components like SMPSs

Closed 2019-02-25.

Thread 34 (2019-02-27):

use only one Si5324 output

sbourdeauducq, 2019-02-27:
The two outputs are not synchronized (two different dividers) so they cannot be used in a det-lat scenario.

We need WR anyway so the circuit with the ADCLK mux (like on the AMC) is good.

gkasprow, 2019-02-27:
do we really need 3 outputs? If so, I will replace LTC6957 with ADCLK944 since we don't need a mux

gkasprow, 2019-02-27:
first read, then write :) OK, I will copy AMC side clocking..

sbourdeauducq, 2019-02-27:
We need a mux. The RTM needs WR just like the AMC.

gkasprow, 2019-02-27:
OK, done.
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

Closed 2019-02-27.

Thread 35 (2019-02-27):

more SYSREFs to FPGA

sbourdeauducq, 2019-02-27:
Right now there is only one SYSREF (and it seems to be not even properly connected).
Ideally, we want two SYSREFs on each FPGA (RTM and AMC). See here:
https://github.com/sinara-hw/sinara/issues/574#issuecomment-467014358

gkasprow, 2019-02-27:
I can scrap one GTH clock that goes to the 227 bank.

sbourdeauducq, 2019-02-27:
Commented in the wrong issue?
This is about the SYSREF signals on the RTM. I believe this is resolved.

sbourdeauducq, 2019-02-27:
Or you mean, removing a GTH clock to make room for a SYSREF in the AMC/RTM connector?

gkasprow, 2019-02-27:
Yes. I connected 2 SYSREF signals to the RTM FPGA and only one to AMC FPGA.

sbourdeauducq, 2019-02-27:
OK in that case yes:
* remove GTH clock to bank 227
* replace with SYSREF that goes into the same bank as the CDR clock (We will try to use DDMTD this time, not simple 125/150 sampling).

sbourdeauducq, 2019-02-27:
And make sure that the CDR clock goes to a GC.

gkasprow, 2019-02-27:
OK, the LVDS30 pair is used instead of GT clock
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

it is routed to the HMC output from one side
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

and AMC FPGA input from other side, just about the CDR clock input
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

Closed 2019-02-27.

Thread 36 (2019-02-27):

bank 34 does not have voltage indication on schematics

sbourdeauducq, 2019-02-27:
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

sbourdeauducq, 2019-02-27:
Also there is something not right with that voltage. The oscillator is 3.3V, the HW_ID resistors are 2.5V and LVDS requires 2.5V (we have only HR banks with LVDS_25). I suppose the oscillator should output 2.5V levels instead.

sbourdeauducq, 2019-02-27:
Also, is the resistive divider that brings the 50MHz oscillator output to 2.2V something that you have done before and which yields good SI?
What about using a LVDS oscillator instead?

gkasprow, 2019-02-27:
fixed. It is 3.3V

sbourdeauducq, 2019-02-27:
3.3V doesn't work for LVDS.

sbourdeauducq, 2019-02-27:
Did you mean 2.5V?

gkasprow, 2019-02-27:
Bank 27 is connected to 3.3V to provide signaling for HMC chips and mezzanines. Other banks are connected to 2.5V and LVDS are located there.

Closed 2019-02-27.

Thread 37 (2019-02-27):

resistive divider for 50MHz oscillator

sbourdeauducq, 2019-02-27:
@gkasprow is the resistive divider that brings the 50MHz oscillator (OSC1) output to 2.2V something that you have done before and which yields good SI?
What about using a LVDS oscillator instead?

sbourdeauducq, 2019-02-27:
Alternatively, scrap that oscillator - we can use the path through the GTP (OSC2) like we do on Kasli.

gkasprow, 2019-02-27:
it is close to the FPGA. Impedance matching could be better. I can increase the R37 and keep effective R of roughly 50hm. CMOS oscillators are much cheaper than LVDS ones. I found it useful for testing.

gkasprow, 2019-02-27:
this gives Z=51Ohm
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

jordens, 2019-03-03:
I'd actually scrap OSC1.

Closed 2019-02-27.

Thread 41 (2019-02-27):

consider increasing i2c pullup resistances

jordens, 2019-02-27:
Now there are at least 4 2k2 in parallel and up to ~10 worst case. I'd go for 10k pullups. I think we have the same for Banker etc.

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

gkasprow, 2019-02-27:
done

gkasprow, 2019-02-27:
done for Sayma AMC as well

Closed 2019-02-27.

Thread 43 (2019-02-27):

observing DAC output for debugging

sbourdeauducq, 2019-02-27:
What is the plan for looking at the DAC outputs during initial board bring-up?
Should we make minimalistic AFEs with just balun transformers and connectors?

gkasprow, 2019-02-27:
There is already one - the TestMod.

gkasprow, 2019-02-27:
Look [here](https://github.com/sinara-hw/TestMod/wiki)

sbourdeauducq, 2019-02-27:
Okay, good. We will need them for firmware development.

gkasprow, 2019-02-27:
I have 4 pcs so far.

sbourdeauducq, 2019-02-27:
We need at least 2 for DAC synchronization tests. At least 3 would be more convenient.

hartytp, 2019-02-27:
> I have 4 pcs so far.

Is that with the proper stack up? If so, can you lend me one at some point to stick it on the VNA?

gkasprow, 2019-02-27:
I didn't measure them yet so I cannot confirm. They are supposed to be with the right stackup.

hartytp, 2019-02-27:
Cool. Well, if you send me one I'm happy to have a look.

gkasprow, 2019-02-27:
OK.

Closed 2019-02-27.

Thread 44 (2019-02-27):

swapping FPGA banks 14 and 34

gkasprow, 2019-02-27:
@sbourdeauducq
I've just discovered that "When CFGBVS is connected to GND, the VCCO of Bank 0 must be 1.8V, and if the I/O in Banks 14 or 15 are used for configuration, then the VCCO for the Banks (14 and 15) must also be 1.8V.
Violating this rule will result in configuration failures."
Since we use 3V3 config levels, bank 14w where CFG_DIN is must be also connected to 3V3.
So I want to swap bank 14 and bank 34. They have identical properties.
I will update xls pin files

sbourdeauducq, 2019-02-27:
Urgh, good catch.

gkasprow, 2019-02-27:
I changed also power delivery to the banks so can close it.

Closed 2019-02-27.

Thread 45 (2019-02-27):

spare GTP channels

sbourdeauducq, 2019-02-27:
https://freenode.irclog.whitequark.org/m-labs/2019-02-27#1551260565-1551262342;

gkasprow, 2019-02-27:
Interesting idea.
 But we decided that we will utilize all RTM connector pins to LVDS for AFE.
Is there any use case for RTM FPGA having access to the AMC side FMC?

jordens, 2019-02-27:
I meant routing the GTPs to the RTM-AFEs (via their FMC connector), not to the AMC-FMC.

gkasprow, 2019-02-27:
OK, this makes sense. We can do that.
Just don't use FMC name. It stands for the FPGA Mezzanine Card. I call these AFE connectors :)

gkasprow, 2019-02-27:
which SATA shall I keep?

gkasprow, 2019-02-27:
we can use pins e31/e32 and b31/b32

gkasprow, 2019-02-27:
I mean master or slave SATA?

jordens, 2019-02-27:
Master SATA (the one that connects with a crossover cable to J16 on the AMC and to Kasli) is fine. There are crossover cables IIRC easily available.

gkasprow, 2019-02-27:
done

jordens, 2019-03-03:
And in general we should remove those "slave SATA" things everywhere and turn them all into a single SATA pinout. The RX-TX crossover is easily done in the cable and does not restrict the connectivity options.

elektron314, 2020-07-07:
does sata cable really have crossover inside of it?

sbourdeauducq, 2020-07-07:
You can find some special cables that do; they are rare but they exist.

elektron314, 2020-07-07:
so if I plan to connect two devices with SATA I need to make TX at 2,3 pins and RX at 5,6 pins on one side, and TX at 5,6 and RX at 2,3 on the other side?

sbourdeauducq, 2020-07-07:
I would recommend buying a commercial crossover cable, SATA cables and connectors are messy to tinker with.

elektron314, 2020-07-07:
yes, exactly commercial. But I want to make standard connection, not rare. So do I need to make inverted connection on pcb side because almost all cables are straight?

sbourdeauducq, 2020-07-07:
IIRC I ordered them from https://www.techcable.com/sas-mini-sas-cables/sata-cables/

sbourdeauducq, 2020-07-07:
Yes, almost all cables are straight.

elektron314, 2020-07-07:
thank you, mister! you saved our company!

Closed 2019-02-27.

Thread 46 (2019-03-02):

layout fixes

gkasprow, 2019-03-02:
Mechanical:
- [x] SMA connector clearance with PCB edge - move it 100um outside
- [x] Align J6, J7
- [x] adjust 4-th upper  panel SMA hole
- [x] move T7 away from the board edge
- [x] J16, J18, J55, J66 i J64  not covered vias under connectors
- [x] fix footprint of interdigitated capacitors
- [x] place all power status LEDs in one row

Silkscreen:

- [x] put BaseMod IN/OUT silkscreen on the other layer
- [x] Label on both sides of PCB for name of J1, J2, J73, J74.
- [x] Dot marking pin1 J1, J2, J5, J7, J8, J9, J73, J74
- [x] AFE slot names are not visible when Allaki are installed
- [x] AFE slot names on both sides of PCB
- [x] When the Allaki is mounted, the IN/OUT silkscreen faces the Sayma RTM PCB and makes it useless. Put it on the other layer that is visible when the card is mounted.
- [x] add description to LD12, LD5, LD10, LD11, LD3

gkasprow, 2019-03-13:
-[ ] label all important ICs on the silk
-[ ] add test points to all power rails, slow busses (I2C/SPI) and other important signals. where possible also aim to expose all clocks via ufl or similar (e.g. if there is an unused output on a clock buffer then connect it to a UFL test point)
-[ ] for slow signals, don't make traces + vias unneccesarily small and don't cram components too close together (obviously, feel free to ignore this where it makes a genuine difference to SI/ease of layout, but don't just cram things together where they don't need to be)
-[ ] where possible (particularly slow signals) add 0R resistors that can be used to disconnect the signal and allow injection of an external signal. also consider adding 0R/DNP pull-ups/pull-downs on logic lines
-[ ] make sure that there is some accessible (e.g. by scratching off solder mask) ground/grounded test-points scattered on the top and bottom side
etc. Just standard good practice. This kind of thing makes debugging the EEMs much easier than debugging Sayma

Closed 2019-04-26.

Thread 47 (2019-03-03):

I2C switch reset

jordens, 2019-03-03:
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

Please allow the I2C switch to be reset by the FPGA. Maybe use the SI5324_INT_ALM FPGA pin (I think we don't need that, c.f. https://github.com/sinara-hw/Sayma_AMC/issues/5#issue-391098956).

gkasprow, 2019-03-06:
done

Closed 2019-03-06.

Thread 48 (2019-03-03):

drive AFE REF clock inputs from HMC7043 and not from upstream ADCLK948

jordens, 2019-03-03:
Just a choice to consider:

* there are two unused HMC7043 outputs
* would allow a bit of power saving and configurability
* would allow configurable REF frequency for the AFE
* might be slightly better or slightly worse phase noise (si549 vs hmc830 and external ref vs hmc830)

hartytp, 2019-03-05:
hmmm...The use case I have for these ref lines would be supplying the reference for a 3GHz LO PLL on the AFE mezzanine. The long-term phase stability of the LO is crucial (more important than the DAC clock due to higher frequency), so I'd like to keep the number of components in the clock path to an absolute minimum. Adding the HMC830 + HMC7043 essentially act as a fanout for the 125MHz seems like a lot of extra components that could add extra drift. It may be fine in practice, but that's not obvious without testing.

Obviously, if other people need the extra flexibility of the HMC830 + HMC743 then that could outweigh these risks, but unless anyone presents a concrete use-case, I'd prefer to just use a fanout buffer.

gkasprow, 2019-03-05:
If someone wants a high-frequency clock on the mezzanine, it can always install there a copy of HMC chipset when needed. I can also add an assembly option but there will always be some crosstalk...

jordens, 2019-03-06:
Would the upstream recovered clock stability be degraded by this? It's going to be limited by the distribution and DDMTD recovery stability.

hartytp, 2019-03-06:
> If someone wants a high-frequency clock on the mezzanine, it can always install there a copy of HMC chipset when needed. I can also add an assembly option but there will always be some crosstalk...

Yes, for MixMod (which is currently the only place we have plans to use this reference on the AFE) we will install an HMC830.

> Would the upstream recovered clock stability be degraded by this? It's going to be limited by the distribution and DDMTD recovery stability.

Until we've done a thorough audit of the stability/noise contributions of each component in the clock chain, it's not clear what the limitations will be.

nonetheless, keeping clock chains as simple as possible is generally good practice. So, the question is whether we envisage any scenarios where the HMC7043 would be helpful. Right now, I don't see any. The only AFE currently intended to use the reference is MixMod, which will have an HMC830 on it to produce the LO (the LO will be at a higher frequency than the DAC clock, so we can't produce it by directly from the HMC7043 output).

Let's try to just keep this as simple as possible...

jordens, 2019-03-06:
I'd operate under the assumption that DDMTD will worse than the HMC830 on those timescales. I don't see how using the upstream ports instead of the downstream ports is simpler. Unloading and maybe even eliminating that fanout would definitely be a simplification. And MixMod is quite a bit down the road. The simplest possible and best stability approach would be to feed MixMod externally. But well. IMO not worth arguing now.

hartytp, 2019-03-06:
> And MixMod is quite a bit down the road

Right now any application at all for this reference pin is quite a bit down the road. BaseMod certainly won't use it.

Let's just stick with the fanout. Once we have some data from Sayma v2.0 and a clearer picture of potential use-cases we can revisit this decision.

Closed 2019-03-06.

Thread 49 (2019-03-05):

HMC830 active loop filter

hartytp, 2019-03-05:
Courtesy of @WeiDaZhang, let's use this loop filter topology:

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

Comments:
- Let's stick with the current 3rd order loop filter for the next production run, but add pads for the active 6th order filter. These pads allow us to use either a passive 4th order loop filter or an active 6th order loop filter, see component values below. Please add component choice table to the schematic as an annotation
- NB the HMC830 PFD noise dominates the in-loop noise for the final system assuming a good reference source like a Wenzel oscillator or SI549. So, the optimal loop filter does not depend on the reference source
- The OpAmp could be a LT6018. Ideally, let's run this from a 5V supply
- NB since the charge pump output has a high impedance, we're actually not very sensitive to noise on the OpAmp non-inverting pin, so we don't need a low noise reference to generate this supply; RC filtering from a low-noise LDO is fine
- The higher-order filters used here give very good rejection of out-of-loop spurs (e.g. from WR)

 Component | Passive 4th Order | Active 6th Order
---|---|---
R0 | 1.1k | 0R
C1 | 3n | 51p
R2 | 5.6k | 1.1k
C3 | Short | 2n
L4 | DNP | 8.2u
Rp | 1.1k | 1.1k
C2 | 4.3p | 2.7n
Cp | 30p | 24p
C5 | 1.3p | 3.3n
R3 | Short | 51
Cb1,2 | DNP | 0.1u//100p
Rb1,2 | DNP | 1k
R4 | 22k | DNP

hartytp, 2019-03-05:
To remind, the main motivation for using the active loop filter will be if we find phase stability in the passive loop filter. So, the methodology will be to test using the current loop filter and not bother with the active loop filter unless we find a reason to.

@gkasprow please make sure that the loop filter is as compact as possible (small loop area) and routed away from all noise sources (SMPSs etc) to minimise pickup. Thanks!

hartytp, 2019-03-05:
Simulation files for these loop filters...

[Archive.zip](https://github.com/sinara-hw/Sayma_RTM/files/2932831/Archive.zip)

gkasprow, 2019-03-05:
@hartytp are U sure we want inverting amplifier filter?

WeiDaZhang, 2019-03-06:
> are U sure we want inverting amplifier filter?

Very good point. Thanks @gkasprow
All the active filter topologies provided in the Hittite PLL software are inverting.
And, these loop filters can be simulated with HMC830.
So, I was assuming the HMC830 can work with inverting active filter.

Yes, and no, after checked.
It doesn't work by default, a bit in the registers needs to be set.
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
But overall, it should be fine.

hartytp, 2019-03-06:
Right, the HMC830 can nominally work with active loop filters by setting the pd_phase_sel bit, so I do not anticipate a problem here. But, I haven't tested this in action yet. Will test once the new hw arrives.

gkasprow, 2019-03-11:
@hartytp don't you mind if I replace LT6018 with something that has standard pinout, like ADA4528?
I also have LT6018 in my libs so it doesn't make any difference which I use but later on, it would be hard to replace it with another type.
The loop filter schematic is here. 0R resistors (R148, R142) will not be mounted.
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

hartytp, 2019-03-11:
@weidazhang ^

hartytp, 2019-03-11:
Afaict it’s fibe. Need to check the common mode input range and noise

gkasprow, 2019-03-11:
ADA4528 has much higher noise (5.6 nV/√Hz) but it is rail to rail.

gkasprow, 2019-03-11:
LT6018 needs at least 8V supply,  input range is from 3V above the supply rail, so we would need a negative supply with possible power sequencing issues. I'd prefer opamp supplied from 5V

hartytp, 2019-03-11:
If we're happy going for a TSOT package, there are a few nice options like LT623{036}

Anyway, I'll leave the final call to @WeiDaZhang since he's thought about this more.

gkasprow, 2019-03-11:
SO-8 is also fine.

WeiDaZhang, 2019-03-12:
No objection to ADA4528 nor LT6236, though ADA4528 is more compatible with other OpAmps. the OpAmp noise is well covered by the PD noise.

Closed 2019-04-08.

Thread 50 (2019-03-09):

DAC output -> fast comparator -> RTM FPGA input

sbourdeauducq, 2019-03-09:
Is it realistic to add such a path on Sayma RTM?

* Useful as a built-in self-test to check that DAC outputs are toggling *and* synchronized to the FPGA.
* One path for each DAC.
* AMC FPGA generates test pattern on JESD204 which is timed by DDMTD core on RTM FPGA.
* RF switch on AFE can be used to disable output during BIST.
* The fast comparator could potentially be a hacked LVDS input buffer in the FPGA, with proper signal conditioning.
* Maximum DAC frequency is 1.2GHz. Maximum data rate received correctly by the FPGA is rated at 1250MBps (625MHz). We can either add a RF switch to avoid overloading the FPGA input, or just hope that it won't cause any ill effects. Based on past experience with Sayma, I prefer the former option.
* If we use an external comparator, the RF switch action can be effected by driving the other comparator input out of DAC range.

hartytp, 2019-03-09:
Comments/thoughts:
- What if we put this extra DFF on BaseMod/TestMod rather than on Sayma RTM directly? That way we can easily make modifications later on, or remove it once we're satisfied that it's no longer needed.
- I assume that what we'd do is use resistors to pick off a fixed amount of power from one channel on each DAC. Route that to a fast comparator on the AFE mezzanine. Ideally use a comparator with enable input. Can we get away with AC coupling? Then route the comparator output through the FMC connector to a LVDS input on the RTM FPGA.

hartytp, 2019-03-09:
Both OnSemi and ADI have ranges of fast comparators. The amount of power we pick off can be really quite small if done properly, so this needn't interfere with the DAC's normal operation.

Anyway, if we are happy putting this on the AFE then we don't need to delay freezing the RTM schematics, and it's also lower risk since it's cheap to make new AFEs if we mess it up...

sbourdeauducq, 2019-03-09:
Yep, putting it on the AFE sounds good.
If we put an I2C EEPROM on the AFE to identify it, we can even autodetect whether those comparators are there, and skip the test when they aren't.

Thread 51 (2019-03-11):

GPIO/debug port

sbourdeauducq, 2019-03-11:
Can we have a GPIO header going to the FPGA where we can connect signals in case of unexpected problems? Include GC pins, and differential pairs.

gkasprow, 2019-03-11:
We already have. I moved it to another bank to have access to SRCC and MRCC clock pins. I will also route them as diff pairs.
The CLK50 was moved to the 3V3 bank.
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

Closed 2019-03-11.

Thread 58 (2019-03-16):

dac channels cross-wired

hartytp, 2019-03-16:
@gkasprow there is probably a good reason for this, but to double check... Why are the DAC channels cross-wired (OUT0 on the DAC goes to DAC_OUT3 on the AFE etc)? If there is a good reason for this, should we add an annotation to alert users?

gkasprow, 2019-03-16:
such wiring gives straight DAC-AFE traces.

Closed 2019-04-08.

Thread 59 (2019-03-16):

dnp active loop filter

hartytp, 2019-03-16:
Maybe it is already DNPd, but that's not shown on the schematics you posted?

gkasprow, 2019-03-16:
True, The AD crashed at a certain moment and even though all files were saved, the recent variant configuration was lost. Anyway, I'm very happy with AD19 - it crashed only a few times this year while AD17 used to crash a few times per day. The good thing with AD19 is that even with a crash, one loses max 10mins of work. Previous AD versions used to stop doing backups without any warning.
Mentor tools save schematic after every modification, but PCB needs manual saving because of the automatic one works sometimes.

Closed 2019-04-08.

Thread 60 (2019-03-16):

LDO Vset bypass

hartytp, 2019-03-16:
All the LDO Iset capacitors are electrolytic. What's the reason for that when we've always used ceramic for this elsewhere? Does it actually affect the cost? It's a relatively low set current (100uA) se we are somewhat sensitive to capacitor leakage if we actually want to achieve the LDO's rated performance (if we don't need the ultra-low noise then we should just use a cheaper LDO).

gkasprow, 2019-03-16:
I used them due to lower noise, especially microphonic noise caused by the piezo effect that is a nightmare in low noise circuits with big X7R capacitors...
If we use big ceramic ones, one can notice vibrations from fans in output spectra :)

hartytp, 2019-03-16:
ACK. Fair enough. I've never seen issues with microphonics in this kind of application, but maybe the  uTCA fans vibrate more than I'm used to

gkasprow, 2019-03-16:
It depends how deep you dig with spectrum analyzer :D
I probably overestimated the influence of this effect on LDO performance, but it's better to be too careful than to ignore it.

hartytp, 2019-03-16:
okay, sounds good to me.

Closed 2019-03-16.

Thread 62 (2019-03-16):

WR connections

hartytp, 2019-03-16:
There are a few things that seem odd about the WR connections. I've already filed issues about these on Sayma AMC, so just copy the design across to the RTM when it's updated on the AMC.

hartytp, 2019-03-16:
e.g. we have LVPECL bias resistors even though it's a LVCMOS oscillator etc.

Closed 2019-04-08.

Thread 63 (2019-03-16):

replace UFLs with MMCX?

hartytp, 2019-03-16:

sbourdeauducq, 2019-03-24:
https://github.com/sinara-hw/Sayma_AMC/issues/63#issuecomment-475515022

jordens, 2019-03-24:
To me u.fl seems preferable. Doesn't need through holes, uses less space, thinner cables.

gkasprow, 2019-03-24:
UFL connectors consume space only on a single layer while MMCX use a lot of space on all the layers so I use them only in the places that will be used more often.

Closed 2019-04-08.

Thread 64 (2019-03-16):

check HMC830 connections match dev kit

hartytp, 2019-03-16:
Looks okay to me from a quick skim, but would be good for someone to double check

marmeladapk, 2019-04-02:
@hartytp I already checked this during previous design review round and wrote my comments here: https://github.com/sinara-hw/sinara/issues/481.

My only worry is that we're implementing something blindly without understanding these connections. @gkasprow @hartytp What do you think about adding jumpers to each of these pins so that they can be floated?

hartytp, 2019-04-02:
@marmeladapk ack. If you can fit that many 0402 resistors around the chip without layout issues (e.g. we mustn't make critical signals like the loop filter larger to accommodate them) then jumpers are fine.

It's a bit tough to know what to do, since I've had experience with HMC830 giving pins special functions used in diagnostic modes that are only cryptically documented at best. So, reading the datasheet alone, one can end up with a non-working design. Thus, it's usually best to follow the eval board since that can be tested off-line easily. I'd be more relaxed if the HMC830 worked well on *all* of the current Sayma boards, but AFAICT that's not true.

FWIW, it also puzzles me a little that the data sheet explicitly says that all NC pins were grounded during characterisation of the chip, yet they're not grounded on the eval board. I would bet that they used the eval board for characterisation, so the data sheet claim is likely incorrect...

gkasprow, 2019-04-08:
Let's follow the eval board schematic.

Closed 2019-04-08.

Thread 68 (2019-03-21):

RTM FPGA needs to see clock before HMC chips

sbourdeauducq, 2019-03-21:
The cascaded HMC chips don't have deterministic phase. The RTM FPGA uses DDMTD and HMC7043 slips to fix that, and it needs a reference. It can use CDR_CLK_CLEAN when that clock is selected, but when it isn't (which will be the case for initial hardware testing) and the external clock SMA is used instead, it's not working.
I suggest routing an output of IC46 to a GC pin of the RTM FPGA.

sbourdeauducq, 2019-03-21:
Also, the signal from that external clock SMA should not be named EXT_100M_RF_IN, since it's not always 100MHz, e.g. we're using the RTIO clock there in the current v1 DDMTD sync setup.

sbourdeauducq, 2019-03-21:
If must be, replace CDR_CLK_CLEAN2 on R1/R2, but it would be nice to have both if possible.

sbourdeauducq, 2019-03-21:
And those two do not *need* to be GCs if the HMC7043 output at the other input of the DDMTD is a GC.

hartytp, 2019-03-21:
> The cascaded HMC chips don't have deterministic phase. The RTM FPGA uses DDMTD and HMC7043 slips to fix that, and it needs a reference

I thought you were doing all that on the AMC FPGA?

sbourdeauducq, 2019-03-21:
No, it's noisy when SAWG is enabled.

sbourdeauducq, 2019-04-04:
@gkasprow Ping. This is important to get the DAC sync working well.

gkasprow, 2019-04-08:
I connected another ref clock from IC46 to MRCC input of the RTM FPGA.

gkasprow, 2019-04-08:
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

gkasprow, 2019-04-08:
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

Closed 2019-04-08.

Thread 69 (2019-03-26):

N12V0A/P12V0A diodes?

hartytp, 2019-03-26:
@gkasprow I think the answer to this is "no" but to double check....

Do we need diodes on the P12V0/N12V0 lines to ensure that they start up correctly (i.e. to avoid the usual issues where one rail turns on too fast and reverse-biases the other one via OpAmp protection diodes etc)? Currently there are no such diodes on BaseMod, but with all channels populated there could be quite a lot of reverse current.

gkasprow, 2019-03-26:
This issue was observed at the output of the LDOs.
I already implemented them.
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

gkasprow, 2019-03-26:
I implemented them on BaseMod. Sayma RTM has increased startup time of the  -6V converter so it will start later than +6V

hartytp, 2019-03-26:
What about the p and n 12v?

gkasprow, 2019-03-26:
we did not observe such issue with these rails. I can increase the startup time of -12V converter.

hartytp, 2019-03-26:
Ok. Ime these kinds of issues are quite dependent on what kind of load is present. Personally I’d stick the diodes there to be safe.

gkasprow, 2019-03-26:
do you mean diodes at the DC/DC converter output? such diodes are already part of the buck converters.

hartytp, 2019-03-26:
yes, sorry, you're right. This is an issue for LDOs, not bucks.

Closed 2019-03-26.

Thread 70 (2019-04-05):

Missing files

marmeladapk, 2019-04-05:
These files are in the project and are missing from repository.
- RTM_CON.Harness
- I2C_Switch_temp_sens.Harness
- CLK_HMC7043.Harness
- Si5324_CLK_RECOVERY.Harness
- PWR_buck_FPGA_EXAR.Harness
- RTM_IPMI.Harness
- FPGA_7A35T.Harness
- FPGA_7A35T_GTP.Harness
- Clock_Distribution_PLL.Harness
- DAC_AFE_Mezzanine.Harness
- DAC_JESD204B.Harness
- Si5324_CDR_WR_clocks.Harness
- HMC830_CLK_DIST.Harness

marmeladapk, 2019-04-24:
SI5324_CLK_RECOVERY.Harness is still missing. IT should probably be just removed from the project.

Closed 2019-04-26.

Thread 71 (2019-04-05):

Capacitor between DXP and DXN

marmeladapk, 2019-04-05:
MAX6642A datasheet states: "DXP: Combined Remote-Diode Current Source and ADC Input for Remote-Diode Channel. Place a 2200 pF capacitor between DXP and GND for noise filtering".

Should we implement this? There is 2nF worth of capacitors on AMC between DXP and DXN.

gkasprow, 2019-04-07:
Added 2nF

Closed 2019-04-07.

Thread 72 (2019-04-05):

EN_PWR_HMC830 is shorted to ground

marmeladapk, 2019-04-05:
Importer glitch, near IC23.

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

gkasprow, 2019-04-08:
fixed

Closed 2019-04-08.

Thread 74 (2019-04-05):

C448 is not grounded

marmeladapk, 2019-04-05:
GND port is too high (compare with C592).

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

Closed 2019-04-07.

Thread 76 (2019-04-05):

Ground VP_0, VN_0?

marmeladapk, 2019-04-05:
UG480 says that "This pin should be connected to GND if not used."

@jordens , you raised https://github.com/sinara-hw/sinara/issues/495 , is that correct? On Kasli these pins are shorted to ground through ferride bead.

jordens, 2019-04-05:
Kasli was originally
https://github.com/sinara-hw/sinara/issues/349#issuecomment-361272857
Vrefp and vrefn should be grounded without ferrite IIRC. dunno about vp vn.

gkasprow, 2019-04-07:
shall we short vn and vp to GND on Sayma as well?

Closed 2019-04-07.

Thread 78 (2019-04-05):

DRC & DRC rules

marmeladapk, 2019-04-05:
Regarding DRC rules I have the same comments as in https://github.com/sinara-hw/Sayma_AMC/issues/79.

DRC errors:
- Fatal error should be suppressed on harness legend
- Multiple output pins should be suppressed with targetted no ERC
- DXP floating input pins should be suppressed
- IC50 has floating input pins (Share1 & 2), suppress this error and add a note e.g. "Connect SHARE1 & 2 together if the two outputs of the LTM8049 are paralleled."
- "Net AMC_GT.GT{n}TX has only one pin" -> https://github.com/sinara-hw/Sayma_RTM/issues/54
- Mark net DIO7 as N/C (if it's meant to be disconnected)
- ESDSTRIP2 containing one pin should be suppressed
- Mark IC6.A4 & B4 as N/C
- DAC_AFE_mezzanine sch: ADCn_IN and VCMn are annotations, not net names. Mark them as N/C. Btw @hartytp , should ADC lines be disconnected?  It doesn't make sense to me to have named nets that aren't connected to anything.

DRC warnings:
- T5, T6, T12 have unused subparts. I feel it would be better to show them on schematic and N/C all pins (I hate hidden nets, parts etc. in Altium)
- Helper_DCXO has multiple harness types
- RTM_FPGA_LINK sheet entry on RTM_CON has incorrect harness type
- Unconnected line warnings - not sure how serious they are

Closed 2019-04-26.

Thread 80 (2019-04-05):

AMC_LVDS differential lines swapped polarity

marmeladapk, 2019-04-05:
On top schematic AMC_LVDS.LVDS4_N & P goes to sheet entry AMC_LVDS3_P & N. Same with AMC_LVDS.LVDS18 net name, LVDS8, 9, 10, 11.

gkasprow, 2019-04-08:
fixed

marmeladapk, 2019-11-22:
AMC_LVDS.LVDS18 is not fixed.

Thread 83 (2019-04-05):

INT net label (near IC36) shorts  IPMI_SDA to pin IC36 pin 13

marmeladapk, 2019-04-05:
It lies directly on both wires.
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

gkasprow, 2019-04-08:
Good catch!

Closed 2019-04-08.

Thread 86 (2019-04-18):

P3V3_MP power budget

atcher0, 2019-04-18:
Sum of P3V3_MP current is about 45-50 mA, whereas mTCA specification states that RTM P3V3_MP current should be limited to 30mA (MTCA.4 REQ 4-2).

gkasprow, 2019-04-18:
the power consumption was specified for the worst case scenario. I can change the mezzanine supply limit to 5mA

Closed 2019-04-26.

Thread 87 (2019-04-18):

PI analysis

gkasprow, 2019-04-18:
P2V0 rail under 150% load
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
We are well within the LDO limit. But current density in some places is too high.
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
LDOs were shorted to simulate the whole PDN.
After optimization, the current density does not exceed 55A/mm2
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
and DC drop was lowered twice. Note that most of the DC drop is caused by the inductor DCR
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

gkasprow, 2019-04-18:
P4V0 PDN after optimization
via current
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

current density
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

DC drop is mainly on DCR
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

gkasprow, 2019-04-18:
P6V0 rail after optimization
DC drop is dominated by inductors DCR
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

The current density is slightly high, but lower than 67A/mm2. It cannot be easily lowered.
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

gkasprow, 2019-04-18:
N12V0A PDN. Nothing to optimize
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

gkasprow, 2019-04-18:
P12V0A Nothing to optimize

gkasprow, 2019-04-18:
N6V0: 28mV drop, max I density 22.8A/mm2, I optimized the dropout slightly,

gkasprow, 2019-04-18:
P3V3 looked bad before optimization. After some tweaking it is OK:
drop is dominated by inductors DCR
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

dnadlinger, 2019-04-18:
Out of curiosity, is this HyperLynx? I'm sure I've seen this UI somewhere before…

gkasprow, 2019-04-19:
@dnadlinger Yes, it is. Very similar results are produced by SiWave, but it does not have the 3D mode.

gkasprow, 2019-04-26:
12V rail before optimization
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

and after some tweaking
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

gkasprow, 2019-04-26:
P1V0. Reduction of the drop from 220mV to 57mV
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

gkasprow, 2019-04-26:
P1V2
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

gkasprow, 2019-04-26:
P2V5
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

Closed 2019-04-26.

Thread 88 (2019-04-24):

DAC_JESD204B, AD9154BCPZ - Power supply

filipswit, 2019-04-24:
Power supply could be improved by:

- [x] placing more vias and moving vias before capacitors, or placing solid, same as on oposite side.

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

- [x] placing track PVDD12A through capacitor C37A
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

- [ ] placing via before cap C58A, C55A, C54A
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

gkasprow, 2019-04-24:
Good catch!

gkasprow, 2019-04-26:
in case of C58A etc not much can be done. But distances are so short that it does not really matter.

Closed 2019-04-26.

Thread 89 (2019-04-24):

Internal planes

filipswit, 2019-04-24:
- [ ] GND and power vias should be directly conected to planes.  Thermal reliefs causes dead copper.
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

gkasprow, 2019-04-24:
which AD version do you use? Earlier versions can import rules differently.

marmeladapk, 2019-04-24:
Altium 17 has a single rule, which can define different style of connections to through-pad, smd and vias. AD16 and earlier default to this behaviour seen above.

filipswit, 2019-04-24:
16.1, so that coud be caused by older AD.
What about internal plane 1, in AD16.1 is unconnected.

dhslichter, 2019-04-26:
Not to mention that thermal relief is horrible from an SI perspective...

gkasprow, 2019-04-26:
Under AD19 it looks fine.
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

filipswit, 2019-04-29:
Thermal reliefs were coused by AD16.1, Now I use A19 and it's fine.
But, Plane P2 isn't connected.
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

I don't know what is the purpose of dividing GND plane into two GNDs. It's on 3 negative layers.
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

gkasprow, 2019-05-20:
fixed. It was reminiscent from Xpedition version

Closed 2019-05-20.

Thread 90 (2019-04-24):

HMC830_CLK_DIST

filipswit, 2019-04-24:
A 100nF decap could be placed close to IC16 power input.

filipswit, 2019-04-24:
Via to GND could be fitted. C341 close to IC40
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

gkasprow, 2019-04-26:
fixed
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

Closed 2019-04-26.

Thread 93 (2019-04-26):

Differential pairs

filipswit, 2019-04-26:
Based on Saturn:

Class | Plane | Impedance
-- | -- | --
MGT | External | 95
  | Internal | 86
LVDS | External | 96
  | Internal | 93

- [x] Generally there are missing vias connecting reference planes.

- [x] Helper_DCXO could be improved by omission Mid-2 layer (blue one)
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

- [x] AMC_GT.GT0TX kind of right angle
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

- [x] GT16TX can be straighten
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

- [x] MEZZ0_LVDS5 aren't well coupled
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

- [x] MEZZ0_LVDS6 right angle
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

filipswit, 2019-04-26:
Looks like these signals on botom layer don't have solid reference plane under them.
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

gkasprow, 2019-04-26:
we don't really care about power plane below user IO lines.

Closed 2019-04-26.

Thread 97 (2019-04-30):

layout improvement: vias

filipswit, 2019-04-30:
By moving vias, planes will be connected directly instead of by wires.
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

gkasprow, 2019-04-30:
@filipswit many issues were fixed in the latest release. Do you look at the recent file?

filipswit, 2019-04-30:
@gkasprow I have yesterday's version.

Closed 2019-05-20.

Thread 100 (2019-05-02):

Layout chech cross talk

hartytp, 2019-05-02:
Apologies if this is stating the obvious but: during the layout review please check that all sensitive analog lines (clocks, dac outputs etc) are well separated from noise sources like smps or digital lines. I’m particularly concerned about the afe dio lines (lvds adc) so let’s do everything we can to screen them from the dac, lo, etc

hartytp, 2019-05-17:
@marmeladapk did you check this when you did your design review? If so, can you close this please?

Same for the other open issues.

marmeladapk, 2019-05-17:
@filipswit

hartytp, 2019-05-17:
@gkasprow @marmeladapk what about all the other open issues? Are these boards ready for manufacture? If so, can the other issues be closed?

marmeladapk, 2019-05-17:
@gkasprow needs to close them once they are done.

hartytp, 2019-05-17:
OKay. But, just to check we're on the same page, the boards aren't ready to send off for manufacture until these are all closed, right? What's the timeline for that? When can we get Sayma to the board house???

gkasprow, 2019-05-20:
I went through this issue and optimised a little the layout increasing separation between ADC LVDS lines.
DAC and LO lines are far away.

Closed 2019-05-20.

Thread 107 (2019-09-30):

No holes for panel

marmeladapk, 2019-09-30:
We're working on a special panel as a bandaid solution for now.

gkasprow, 2019-09-30:
It's easier to glue the panel fixture to the PCB using epoxy. The panel can be always removed because it is latched to the fixtures.

marmeladapk, 2019-12-02:
Additionally holes for AFEs are also not aligned. Not sure if it's a problem on Basemod or on RTM though.

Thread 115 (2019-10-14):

AFE - maximum currents on power supply rails

marmeladapk, 2019-10-14:
During our stress tests we're quickly approaching > 100 W power consumption and testmods do not even pull as much current as they're supposed to do:

| Rail | Current testmod | Theoretical value on sheet |
|------|---------------------------|-------------------------------|
| +12V | 200 mA | 400 mA |
|-12V|100 mA | 100 mA |
|+6V | 1.5 A | 3 A |
|-6V | 100 mA | 200 mA |
|+3V3| 1 A | 1.5 A |

Even with these lower values we exceeds MTCA spec (80W). We can change resistor values to pull as much as we need, however I'm not sure if this is a good idea as we won't be able to supply that much in the final environment (at least not until next MTCA spec with 120 and 240 W power consumption arrive).

How much current do we really need on AFEs? Could we just tone down these requirements?

gkasprow, 2019-10-14:
The power supply system was not designed to simultaneously draw max current from all rails.
That's why I applied such loads.
We should add a constraint on max power consumed by the AFE.

jbqubit, 2020-01-17:
@marmeladapk What did you decide for limiting current to AFE?

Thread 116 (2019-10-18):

DAC SYSREF signal format

sbourdeauducq, 2019-10-18:
What signal format should be programmed into the HMC7043 for DAC SYSREF?
This says "CML HP" (is that a reference to the "high power" mode of the HMC7043?):
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
This says "LVDS" (are the 50 ohm resistors above supposed to convert CML HP to LVDS? Why not use LVDS output directly from the HMC7043 then?):
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

sbourdeauducq, 2019-10-18:
And should this one be configured:
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

gkasprow, 2019-10-19:
the outputs with resistors to GND are LVPECL, the ones without are CML. We need internal resistors in the case of CML. 100R should work. I'm not 100% sure but LVDS probably were not strong enough to drive the DAC.

Closed 2019-10-21.

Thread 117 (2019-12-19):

OpenMMC support

jbqubit, 2019-12-19:
From call on 12/18 with Creotech. OpenMMC is missing several features that preclude full testing of RTM.
- RTM temperature sensors
- RTM hot-swap

What else is missing?

jbqubit, 2020-01-17:
@marmeladapk Does OpenMMC now have full support for Sayma RTM? If so please close. Or indicate what's missing.

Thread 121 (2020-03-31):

photos

jbqubit, 2020-03-31:
Please post photos of the stuffed Sayma_RTM for contract accounting.

> Sayma RTM v2.0: print 10 PCBs, stuff 6

akaminska, 2020-04-07:
1907180PW0009A0103
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

akaminska, 2020-04-07:
1907180PW0008A0104
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

akaminska, 2020-04-07:
1907180PW0008A0107
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

akaminska, 2020-04-07:
1907180PW0008A0105
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

akaminska, 2020-04-07:
1907180PW0008A0106
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

akaminska, 2020-04-07:
1907180PW0008A0108
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

akaminska, 2020-04-07:
Unpopulated PCBs
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

akaminska, 2020-04-10:
Please remember that these panels are "prototypes" as well, we definitely aim for better quality for the final product...
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

jbqubit, 2020-04-10:
Looks good. Thank you!

hartytp, 2020-05-22:
Did anyone take a nice photo of Sayma AMC + RTM with panels fitted?

Closed 2020-04-10.

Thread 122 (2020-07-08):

Si5324 fails to ack

sbourdeauducq, 2020-07-08:
Sometimes happens on some boards:
```
[     0.011435s]  INFO(satman): gateware ident 6.7258.3f0cf6e6.beta;satellite
panic at src/libcore/result.rs:945:5: cannot initialize Si5324:
"Si5324 failed to ack write address"
```

jordens, 2020-07-10:
The log above was from me. I assumed that it was from the AMC but it looks like that I2C bus works fine (lots of successful SI5324 traffic before the error). And then it starts passing RTM messages. On the RTM there is one I2C xfer, which looks nice (low voltage levels at least during the address portion) on both sides of the I2C switch, but still errors. Didn't investigate further.

marmeladapk, 2020-07-10:
Fixed with https://github.com/m-labs/artiq/pull/1483 + https://github.com/m-labs/migen/pull/212 . @hartytp @jordens Please recompile your build with those changes and reopen if necessary.

Closed 2020-07-10.

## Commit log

2019-01-02 v2.0rc1 schematic review
2019-02-27 Altium version
    [CLK_HMC7043.SchDoc, Clock_Distribution_PLL.SchDoc, DAC_AFE_Mezzanine.SchDoc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]
2019-04-01 added missing harness files
    [FPGA_7A35T.SchDoc, Sayma_RTM.PrjPcb]
2019-04-08 added missng files
    [CLK_HMC7043.SchDoc, DAC_AFE_Mezzanine.SchDoc, DAC_JESD204B.SchDoc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]
2019-04-08 component placement done
    [CLK_HMC7043.SchDoc, DAC_JESD204B.SchDoc, FPGA_7A35T.SchDoc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]
2019-04-10 DACs routed, rules added
    [CLK_HMC7043.SchDoc, DAC_AFE_Mezzanine.SchDoc, DAC_JESD204B.SchDoc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]
2019-04-13 95% routing done
    [CLK_HMC7043.SchDoc, DAC_AFE_Mezzanine.SchDoc, DAC_JESD204B.SchDoc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]
2019-04-14 100% routing done
    [CLK_HMC7043.SchDoc, FPGA_7A35T.SchDoc, PWR_Buck_2V_4V_4A.SchDoc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]
2019-04-15 v2.0rc5 PCB review
    [DAC_AFE_Mezzanine.SchDoc, I2C_Switch_temp_sens.SchDoc]
2019-04-15 v2.0rc6 PCB review
    [PWR_Buck_2V_4V_4A.SchDoc, Sayma_RTM.PrjPcb, Sayma_RTM.SchDoc]
2019-04-18 solved some PI issues
    [DAC_AFE_Mezzanine.SchDoc, SI5324_CDR_WR_clocks.SchDoc]
2019-04-26 fixed all PI issues
    [DAC_AFE_Mezzanine.SchDoc, FPGA_7A35T.SchDoc, PWR_SEPIC_N6V.SchDoc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]
2019-04-29 added logo
    [Sayma_RTM.PrjPcb]
2019-09-30 v2.0.1, only BoM changes Fix #104 (changed switching frequency of IC48)
    [PWR_Buck_6V_8A.SchDoc]
